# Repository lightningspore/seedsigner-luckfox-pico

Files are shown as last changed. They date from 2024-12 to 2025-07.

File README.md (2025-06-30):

# seedsigner-luckfox-pico
Port of the SeedSigner code to support the LuckFox Pico Linux board family. Since this device is still an embedded Linux device, like the Raspberry Pi, the changes are fairly minimal in order to access the buttons and the camera. This repo mostly pertains to the Buildroot OS build instructions, the KiCAD schematic and PCB design files, and 3D models of cases for the assembled device.

SeedSigner code fork: https://github.com/lightningspore/seedsigner/tree/0.8.5-luckfox

## Hardware Photos
_Most Recent Iteration: LuckFox Pico Mini B with no onboard SPI flash_
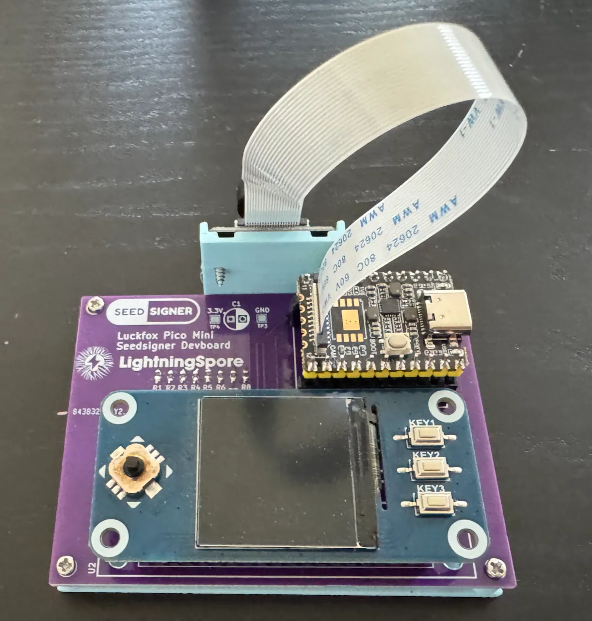
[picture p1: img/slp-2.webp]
LuckFox Pico Mini - SeedSigner

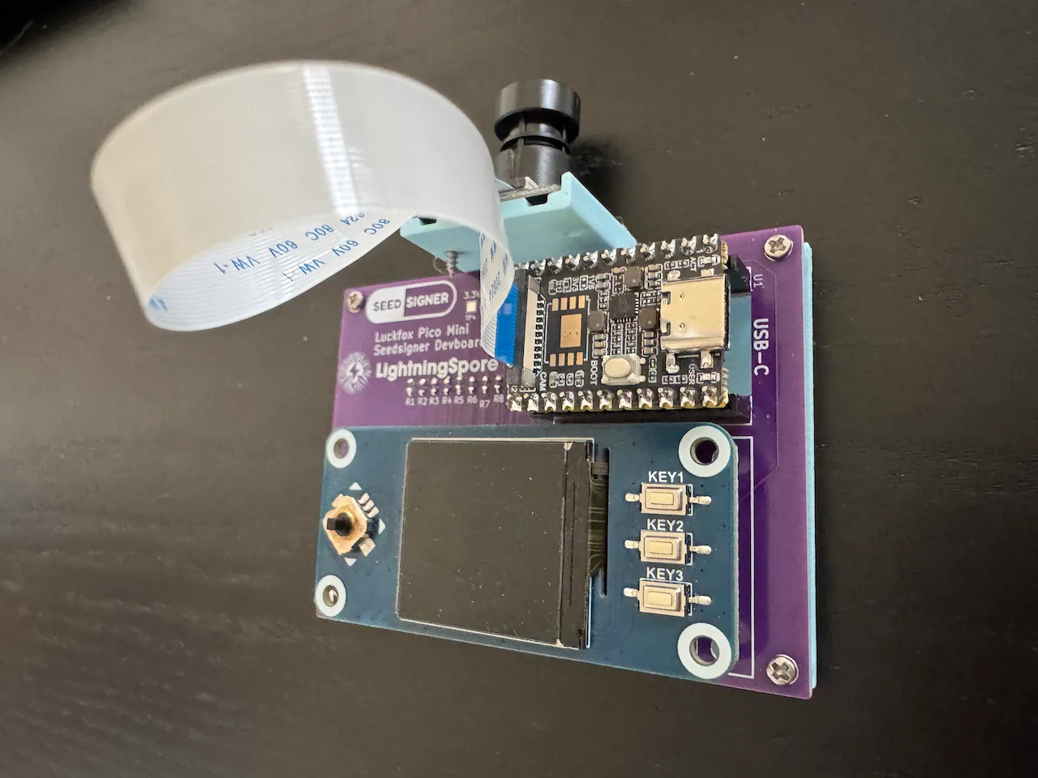
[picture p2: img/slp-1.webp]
LuckFox Pico Mini - SeedSigner 2


_Previous Iteration: LuckFox Pico Pro Max (More Flash, SPI Flash)_
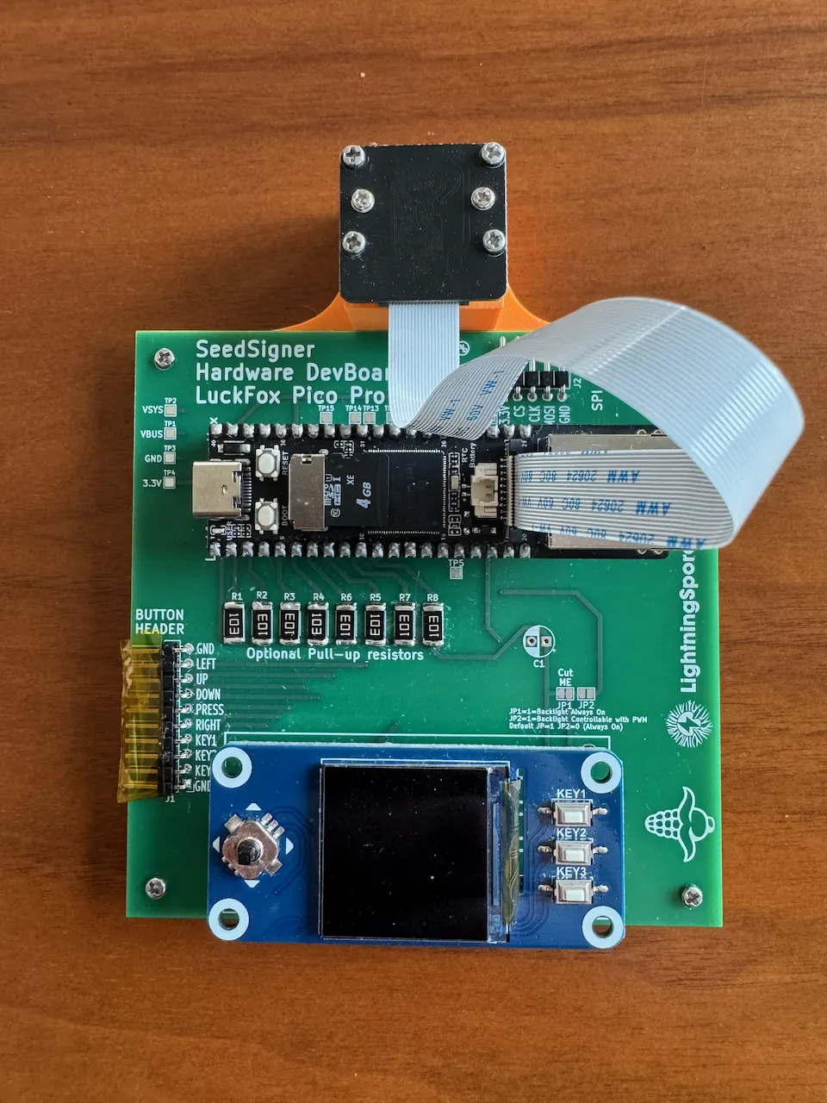
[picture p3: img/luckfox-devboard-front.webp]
LuckFox Pico Pro Max - SeedSigner

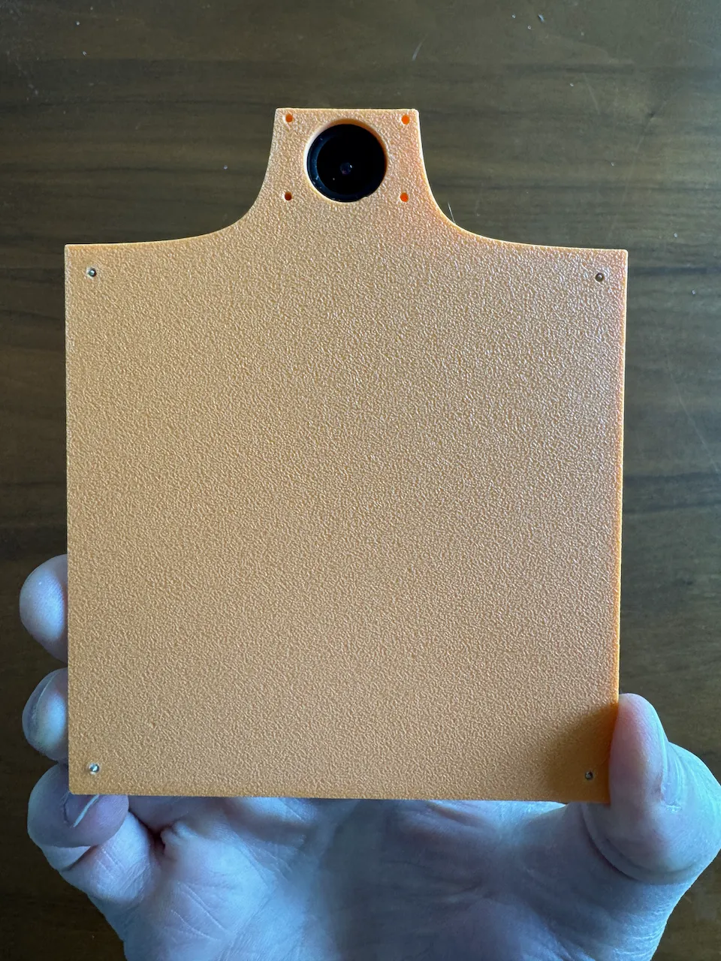
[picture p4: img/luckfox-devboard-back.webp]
Case From Behind


## Demo Videos

### First Look: SeedSigner running on LuckFox Pico Linux devboard
SeedSigner on LuckFox Pico Pro Max (https://www.youtube.com/watch?v=WHkOSn-lPG4)

## Materials Needed
Check out the shopping list for a parts list of various LuckFox-based hardware configurations: [here](docs/shopping_list.md)

These example builds can build a device for around $60.

## OS Image Build with Buildroot
The OS image is built using Buildroot in a Docker container. The complete build instructions, package requirements, and troubleshooting process are documented in [OS-build-instructions.md](docs/OS-build-instructions.md).

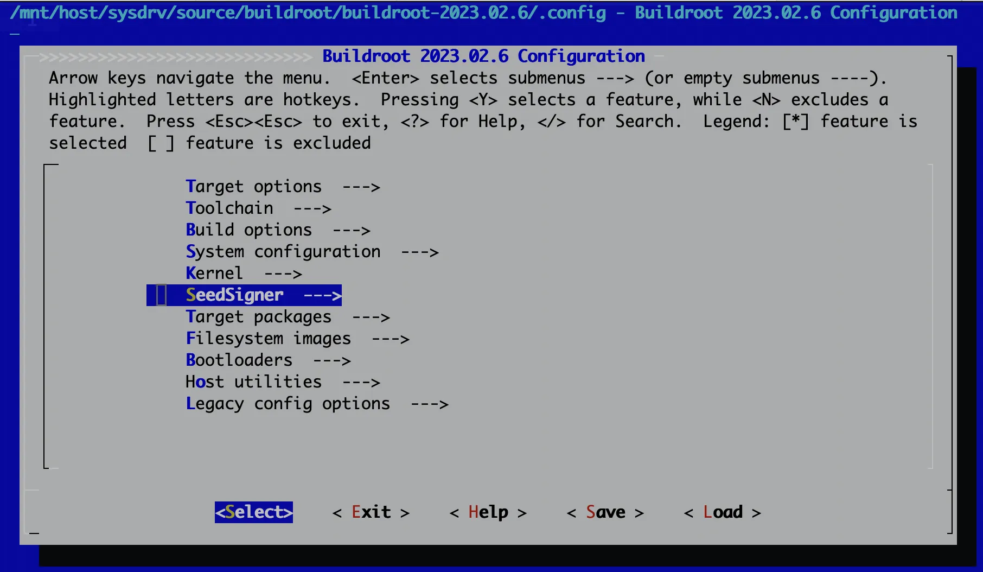
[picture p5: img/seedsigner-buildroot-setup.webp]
Buildroot Prompt


## Dev Machine Setup

### Install ADB
Developing for the LuckFox Pico device is quite convenient since the devices never connect to the internet and you can access the device shell using `adb`. You can push files back and forth to your dev machine, and you can access the device as a shell easily.
```
# mac
brew install homebrew/cask/android-platform-tools

# linux
sudo apt install android-tools-adb
```

### ADB Connection and Device Management

1. Connect to the device:
```
# List connected devices
adb devices

# Connect to device shell
adb shell
```

2. File Operations:
```
# Push files to device
adb push local_file.txt /remote/path/

# Sync the code repo for local development
adb push /repos/seedsigner/src /seedsigner

# Pull files from device
adb pull /seedsigner/config.json .

# List files on device
adb shell ls /path/to/directory
```

## Hardware Identification
Notice the left device has an empty PCB footprint pattern on it. This is where the optional SPI flash is soldered on. For the SeedSigner project we don't want permanent storage, so avoid devices with soldered SPI flash.

```
LEFT:  LuckFox Pico Mini A -> No Flash
RIGHT: LuckFox Pico Mini B -> Soldered Flash
```
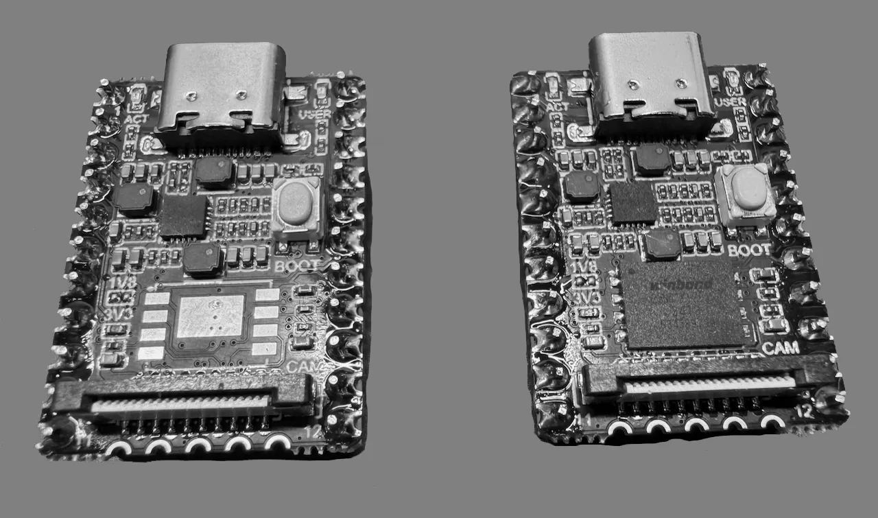
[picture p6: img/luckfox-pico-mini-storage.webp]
LuckFox Pico Mini


## Flashing the Device

### Flash MicroSD Card
```
sudo dd bs=4M status=progress if=seedsigner-luckfox-pico-YYYYmmdd_hhmmss.img of=/dev/diskX
```
Replace `/dev/diskX` with your actual SD card device path.

## LuckFox Pico OS Modifications
We have forked the [LuckFox Pico SDK](https://github.com/lightningspore/luckfox-pico) in order to enable various hardware features like pull-up resistors, adjust video RAM, and other things.

### Camera Memory
The LuckFox devotes some of its memory for camera-related algorithms, but we don't use this feature. Particularly on the LuckFox Pico Mini device, which only has 64MB of RAM, it is beneficial for us to reclaim a bit of this memory.

Memory usage WITHOUT modification:
```bash
[root@luckfox ]# free -h
              total        used        free      shared  buff/cache   available
Mem:          33.0M       24.3M        1.4M      476.0K        7.3M        5.4M
Swap:             0           0           0
```

Memory usage WITH modification:
```bash
[root@luckfox ]# free -h
              total        used        free      shared  buff/cache   available
Mem:          53.0M       23.6M        1.9M      472.0K       27.5M       25.3M
Swap:             0           0           0
```

### Pull-up Resistors
Our current dev board has external pull-up resistors, since we didn't know how to enable these at the time, and it is always smart to plan ahead when designing PCBs. NOTE: Even with this commit and this change, the internal pull-ups don't seem to work.

### SPI Buffer Size
While it is possible to send SPI data in chunks, you can increase the SPI buffer size to slightly increase throughput, which is useful for larger displays.

### PWM Output
In order to control the LCD screen backlight and support true dimming of the display (instead of just changing the background color of the QR code, for example), we had to enable a PWM on a specific output pin.

## Support the Developer
If you find this project helpful and would like to support its development, you can buy me a coffee! Your support helps keep this project going and funds future improvements. Help decentralize Bitcoin hardware!

Buy Me A Coffee (https://www.buymeacoffee.com/lightningspore)

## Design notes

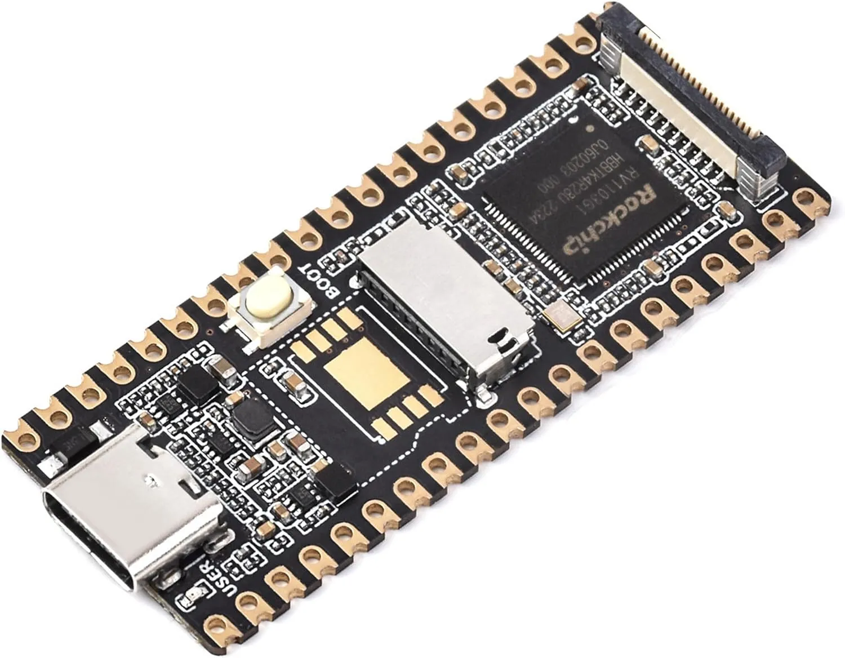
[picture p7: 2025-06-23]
img/luckfox-pico.webp

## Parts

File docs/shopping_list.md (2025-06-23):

# SeedSigner LuckFox Pico Shopping List

This document contains all the materials needed to build your own SeedSigner using the LuckFox Pico Pro/Max development board.

## Hardware Components
There are multiple PCB revisions available in this repository, some which support the Luckfox Pico Pro Max, with its two rows of 20 pins, and some designs supports the Luckfox Pico Mini, with its two rows of 11 pins.

Small form factor, no SPI flash:
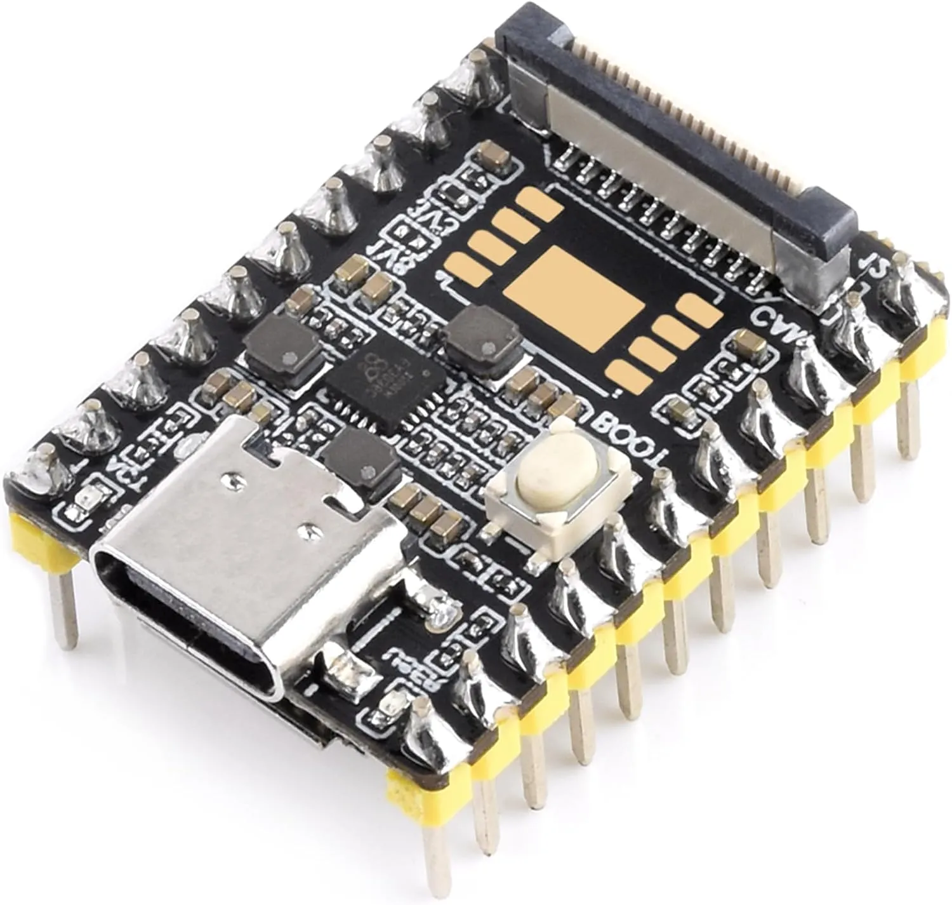
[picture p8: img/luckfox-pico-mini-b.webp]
Luckfox Pico Mini BM


Larger form factor, no SPI flash:
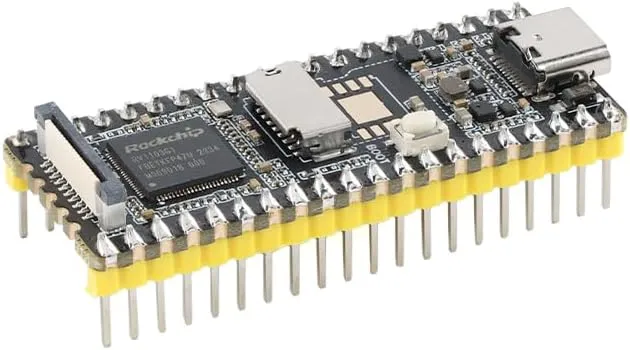
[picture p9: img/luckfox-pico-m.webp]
Luckfox Pico M


Larger form factor, SPI flash, ethernet port:
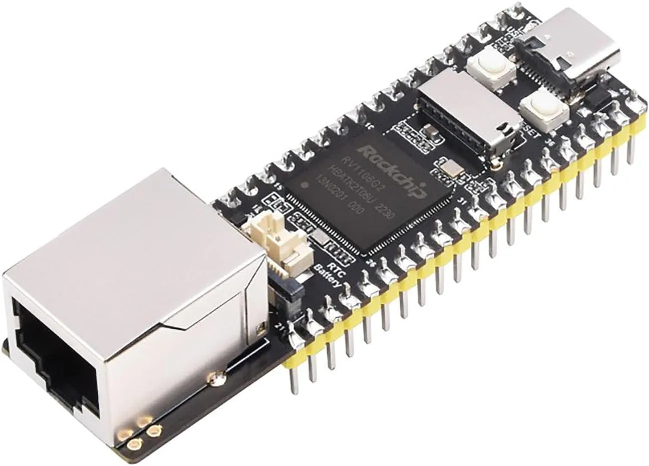
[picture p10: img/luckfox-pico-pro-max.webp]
Luckfox Pico Pro Max


### Core Components
| Item | Price | Link | Notes |
|---|---|---|---|
| LuckFox Pico Pro Max | $20 | [Amazon](https://www.amazon.com/dp/B0D6QVC178) | Main development board |
| LuckFox Pico Mini-BM | $8 | [Amazon](https://www.amazon.com//dp/B0D6VSMND4) | Main development board 2 |

| LuckFox Camera SC3336 | $16 | [Amazon](https://www.amazon.com/dp/B0CJM7S6F6) | Camera module for QR code scanning |
| SeedSigner LCD Button Board | $16 | [Amazon](https://www.amazon.com/dp/B07FDX5PJY) | Display and button interface |

### Connectors & Headers
| Item | Price | Link | Notes |
|---|---|---|---|
| 40 Pin Header | $1 | [Amazon](https://www.amazon.com/dp/B01461DQ6S) | For connecting components |
| 2 x Row Header Male | $0.25 | [Amazon](https://www.amazon.com/dp/B07R5QDL8D) | Additional connectors |

### Custom Parts
| Item | Price | Link | Notes |
|---|---|---|---|
| Custom PCB | $5 | TODO: Link to PCB sales | Custom circuit board |
| 3D Printed Case | $2 | TODO: Link to 3D Printed Case sales | Enclosure for the device |

## Total Cost
**Estimated Total: ~$60** (when ordering from Amazon)

## MicroSD Cards
| Item | Price | Link | Notes |
|---|---|---|---|
| ATP Electronics AF4GUD3A-WAAXX | $13.51 | [DigiKey](https://www.digikey.com/en/products/detail/atp-electronics-inc/AF4GUD3A-WAAXX/5361062) | Recommended microSD card for flashing the custom OS image |

## Hardware Identification Notes

When purchasing the LuckFox Pico board, make sure to get the version **without** the SPI flash footprint. The left device in the reference image shows the correct version with an empty PCB footprint pattern. For the SeedSigner project, we don't want permanent storage, so avoid devices that have the SPI flash already soldered on.

Luckfox Pico Mini

---

*Note: Prices and availability may vary. This list was compiled based on the project documentation and may need updates as components become available or prices change.*

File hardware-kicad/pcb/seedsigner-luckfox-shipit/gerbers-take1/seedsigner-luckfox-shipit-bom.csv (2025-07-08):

Id | Comment | Designator | Footprint | Quantity | JLCPCB Part#(optional) | Comment
1 | Header 8 Pos | LCD1 | ST7789_LCD_MOD1 | 1 | C190820
4 | Resistor 0805 10Kohm | R8,R4,R3,R7,R5,R1,R2,R6 | R_0805_2012Metric_Pad1.20x1.40mm_HandSolder | 8 | C25612
8 | 2 X 20pos 2.54 row header female | U1,U2 | LUCKFOX_PICO | 2 | C25503124

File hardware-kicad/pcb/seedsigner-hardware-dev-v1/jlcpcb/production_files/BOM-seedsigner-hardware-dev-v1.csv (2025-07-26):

Comment | Designator | Footprint | LCSC | Quantity
PCA9539PW_112 | U5 | SOP65P640X110-24N | C129516 | 1
Conn_01x04 | J1 | NS-Tech_Grove_1x04_P2mm_Vertical | C157926 | 1
10K | R1,R10,R11,R12,R13,R14,R2,R3,R4,R5,R6,R7,R8,R9 | R_0805_2012Metric_Pad1.20x1.40mm_HandSolder | C17414 | 14
ST7789 | LCD1,LCD2 | PinHeader_1x08_P2.54mm_Vertical | C190820 | 2
LuckFox_Pico_PLUS_PRO | U4,U6 | LUCKFOX_PICO | C25503124 | 1
RPI_ZERO | U3 | RPi_Zero | C2685093 | 1
0.1uF | C1 | C_0805_2012Metric_Pad1.18x1.45mm_HandSolder | C49678 | 1
WAVESHARE_LCD_BUTTON_BOARD_1.3in | U2 | WAVESHARE_LCD_BUTTON | C5224014 | 1
SW_Push | SW5 | BTN_SPST_NO_PTH |  | 1
TestPoint | TP6 | TestPoint_Pad_D1.0mm |  | 1
SW_Push | SW6 | BTN_SPST_NO_PTH |  | 1
SW_Push | SW2 | BTN_SPST_NO_PTH |  | 1
TestPoint | TP4 | TestPoint_Pad_D1.0mm |  | 1
SW_Push | SW3 | BTN_SPST_NO_PTH |  | 1
TestPoint | TP2 | TestPoint_Pad_D1.0mm |  | 1
SW_Push | SW7 | BTN_SPST_NO_PTH |  | 1
SW_Push | SW1 | BTN_SPST_NO_PTH |  | 1
TestPoint | TP1 | TestPoint_Pad_D1.0mm |  | 1
TestPoint | TP3 | TestPoint_Pad_D1.0mm |  | 1
SW_Push | SW8 | BTN_SPST_NO_PTH |  | 1
TestPoint | TP5 | TestPoint_Pad_D1.0mm |  | 1
SW_Push | SW4 | BTN_SPST_NO_PTH |  | 1
TestPoint | TP9 | TestPoint_Pad_D1.0mm |  | 1
TestPoint | TP7 | TestPoint_Pad_D1.0mm |  | 1
TestPoint | TP10 | TestPoint_Pad_D1.0mm |  | 1
TestPoint | TP8 | TestPoint_Pad_D1.0mm |  | 1

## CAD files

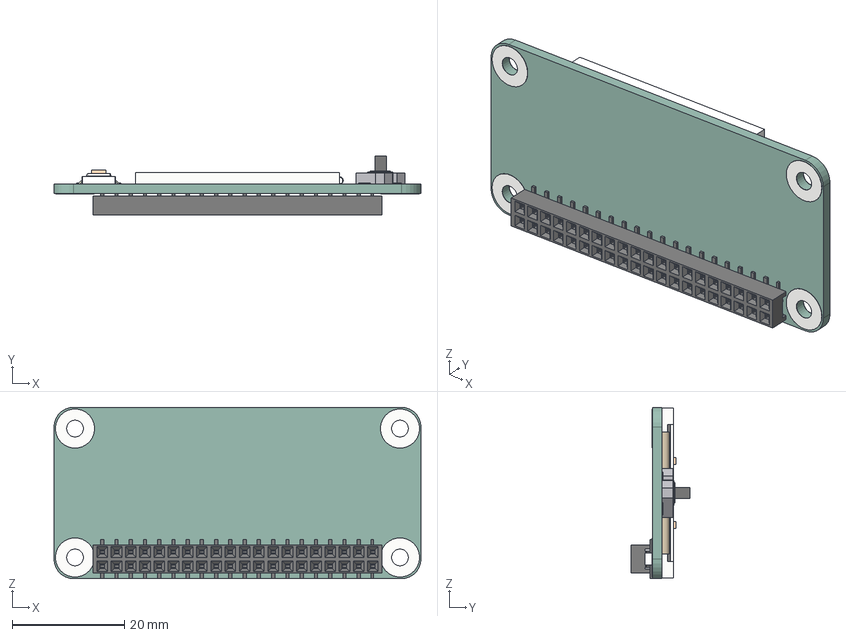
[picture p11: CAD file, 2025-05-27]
hardware-kicad/3d_models/WaveShare 1.44inch LCD HAT v1.step
65.5 x 10.5 x 30.6 mm
silk
glass
plume
joystick
G73 button x 3
DS1023-2x20S v2

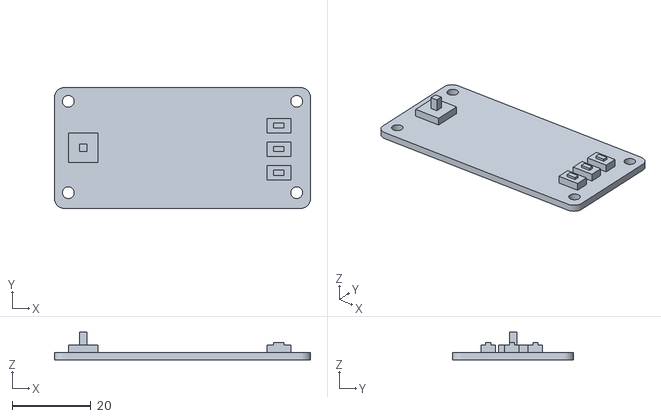
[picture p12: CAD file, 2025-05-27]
hardware-kicad/3d_models/waveshare_lcd_hat.stl
65.0 x 30.7 x 7.00

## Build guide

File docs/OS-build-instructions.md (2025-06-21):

# OS Build Instructions

## Setup the Docker build environment
Run these commands from `buildroot` directory.

Build the builder image:
```bash
cd buildroot/
docker build -t foxbuilder:latest .
```

*IMPORTANT* We need all of these directories to be setup, and cloned in our `$HOME` directory:
```bash
ls ~
luckfox-pico  seedsigner  seedsigner-luckfox-pico  seedsigner-os
```
The `seedsigner-luckfox-pico` directory is this repo we are already in!

Clone the Luckfox SDK repo:
```bash
git clone https://github.com/lightningspore/luckfox-pico.git \
    --depth=1 --single-branch
```

Clone the Seedsigner OS repo:
```bash
git clone https://github.com/seedsigner/seedsigner-os.git \
    --depth=1 --single-branch
```

Clone the Seedsigner repo:
```bash
git clone https://github.com/lightningspore/seedsigner.git \
    --depth=1 -b luckfox-dev --single-branch
```

## Run OS Build

Run these commands from `buildroot/` directory. This is the directory/repo we cloned above.

```bash
LUCKFOX_SDK_DIR=$HOME/luckfox-pico
SEEDSIGNER_CODE_DIR=$HOME/seedsigner
LUCKFOX_BOARD_CFG_DIR=$HOME/seedsigner-luckfox-pico
SEEDSIGNER_OS_DIR=$HOME/seedsigner-os

# TODO check all these above paths exist

docker run -d --name luckfox-builder \
    -v $LUCKFOX_SDK_DIR:/mnt/host \
    -v $SEEDSIGNER_CODE_DIR:/mnt/ss \
    -v $LUCKFOX_BOARD_CFG_DIR:/mnt/cfg \
    -v $SEEDSIGNER_OS_DIR:/mnt/ssos \
    foxbuilder:latest
```

These below commands are run INSIDE of the docker image.

Enter the container:
```bash
docker exec -it luckfox-builder bash
```

Start the build:
```bash
/mnt/cfg/buildroot/add_package_buildroot.sh
```

This commands sets the build targets:
Select, Pico Pro Max, buildroot, and SPI.
```bash
# set build configuration
./build.sh lunch
```

This command allows us to choose what packages to install into our OS image.
```bash
# configure packages to install in buildroot
./build.sh buildrootconfig
```

Buildroot Setup

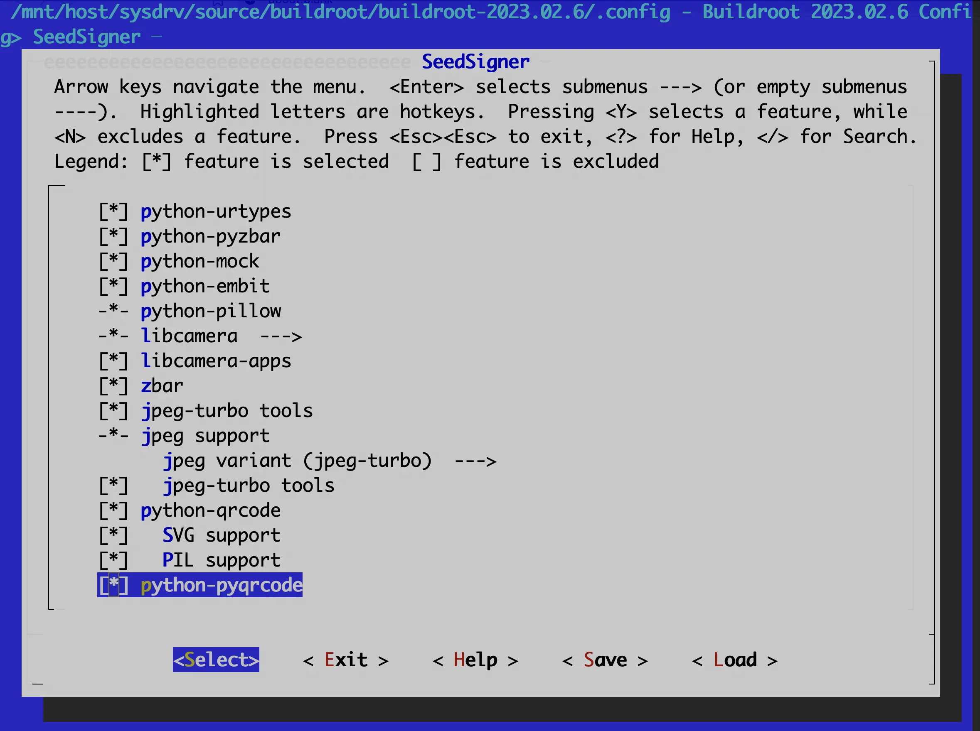
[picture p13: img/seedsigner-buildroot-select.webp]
Buildroot Package Selection


After selecting all the above packages, SAVE the configuration.
The configuration is saved at: `sysdrv/source/buildroot/buildroot-2023.02.6/.config`

You can sanity check your configuration to ensure the selected packages have been enabled like so:
```bash
cat sysdrv/source/buildroot/buildroot-2023.02.6/.config | grep "LIBCAMERA"
cat sysdrv/source/buildroot/buildroot-2023.02.6/.config | grep "ZBAR"
cat sysdrv/source/buildroot/buildroot-2023.02.6/.config | grep "LIBJPEG"
...
```

A final sanity check, this shows all enabled packages... This might be useful as we try and remove any unnecessary packages from the build:
```bash
cat sysdrv/source/buildroot/buildroot-2023.02.6/.config | grep -v "^#"
```

### Adding Custom Packages
If you need to add custom packages to the buildroot configuration, you can use the `add_package_buildroot.sh` script. This script:
1. Adds SeedSigner-specific packages to the buildroot configuration
2. Copies necessary package files from the seedsigner-os repository
3. Updates Python paths and configurations
4. Adds required dependencies like python-pyzbar, python-embit, and camera-related packages

To use the script:
```bash
# From the buildroot directory
./add_package_buildroot.sh
```

This command will use one of the saved configurations for the build:
```bash
# Use config from repo
cp ../configs/config_20241218184332.config sysdrv/source/buildroot/buildroot-2023.02.6/.config

# Sanity check the configuration was loaded properly
# Selected packages like ZBAR should be listed as enabled here
./build.sh buildrootconfig
```

Start the image compilation process:
```bash
./build.sh uboot
./build.sh kernel
./build.sh rootfs
# needed for camera libs
./build.sh media
```

Verify all of the .img files are there:
```bash
$ ls /mnt/host/output/out/           
S20linkmount  media_out  rootfs_uclibc_rv1106  sysdrv_out

$ ls /mnt/host/output/image/
boot.img  download.bin  idblock.img  uboot.img
```

Copy over app code and pin configs
```bash
# Pin configs
cp /mnt/cfg/config/luckfox.cfg /mnt/host/output/out/rootfs_uclibc_rv1106/etc/luckfox.cfg

# Seedsigner code
cp -r /mnt/ss/src/ /mnt/host/output/out/rootfs_uclibc_rv1106/seedsigner
```

Package:
```bash
# Package up the pieces
./build.sh firmware
```

Double check the output, now all of the expected .img files are there:
```bash
$ ls /mnt/host/output/image/
boot.img  download.bin  env.img  idblock.img  oem.img  rootfs.img  sd_update.txt  tftp_update.txt  uboot.img  update.img  userdata.img
```

Final Piece of Sanity Checking:
```bash
dbg='yes' ./tools/linux/Linux_Upgrade_Tool/rkdownload.sh -d output/image/
```

Package into single flashable ISO image:
```bash
cd /mnt/host/output/image
/mnt/cfg/buildroot/blkenvflash seedsigner-luckfox-pico.img
```

Send back to dev machine (if building on a remote X86 machine):
```bash
scp ubuntu@11.22.33.44:/home/ubuntu/seedsigner-luckfox-pico/buildroot/luckfox-pico/output/image/seedsigner-luckfox-pico.img ~/Downloads
```

Flash to MicroSD Card:
```bash
sudo dd bs=4M \
    status=progress \
    if=/Users/lightningspore/Downloads/seedsigner-luckfox-pico.img \
    of=/dev/disk8
```

Put MicroSD Card into Luckfox Pico Device.

```bash
adb shell
```

TODO: Link to next steup in the install/setup process

## Official resources

[Luckfox Pico Official Flashing Guide](https://wiki.luckfox.com/Luckfox-Pico/Linux-MacOS-Burn-Image/) - Official documentation for flashing images to the Luckfox Pico device on Linux and macOS systems

## Hardware Device Overlay Config
```
cat luckfox-pico/sysdrv/source/kernel/arch/arm/boot/dts/rv1103g-luckfox-pico.dts
cat luckfox-pico/sysdrv/source/kernel/arch/arm/boot/dts/rv1103.dtsi
cat luckfox-pico/sysdrv/source/kernel/arch/arm/boot/dts/rv1103-luckfox-pico-ipc.dtsi
cat luckfox-pico/sysdrv/source/kernel/arch/arm/boot/dts/rv1106-evb.dtsi
```

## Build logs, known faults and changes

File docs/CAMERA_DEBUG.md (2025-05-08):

## Ensure CSI is enabled
```bash
cat /etc/luckfox.cfg
```

## Check i2c
```bash
i2cdetect -y 4
```

Check whether 0x30 is UU to verify camera connectivity

```
[root@luckfox ]# which rkipc
/oem/usr/bin/rkipc
```

./

## Forum Links

- [Post 1: I2C and rkisp](https://forums.luckfox.com/viewtopic.php?t=1133)

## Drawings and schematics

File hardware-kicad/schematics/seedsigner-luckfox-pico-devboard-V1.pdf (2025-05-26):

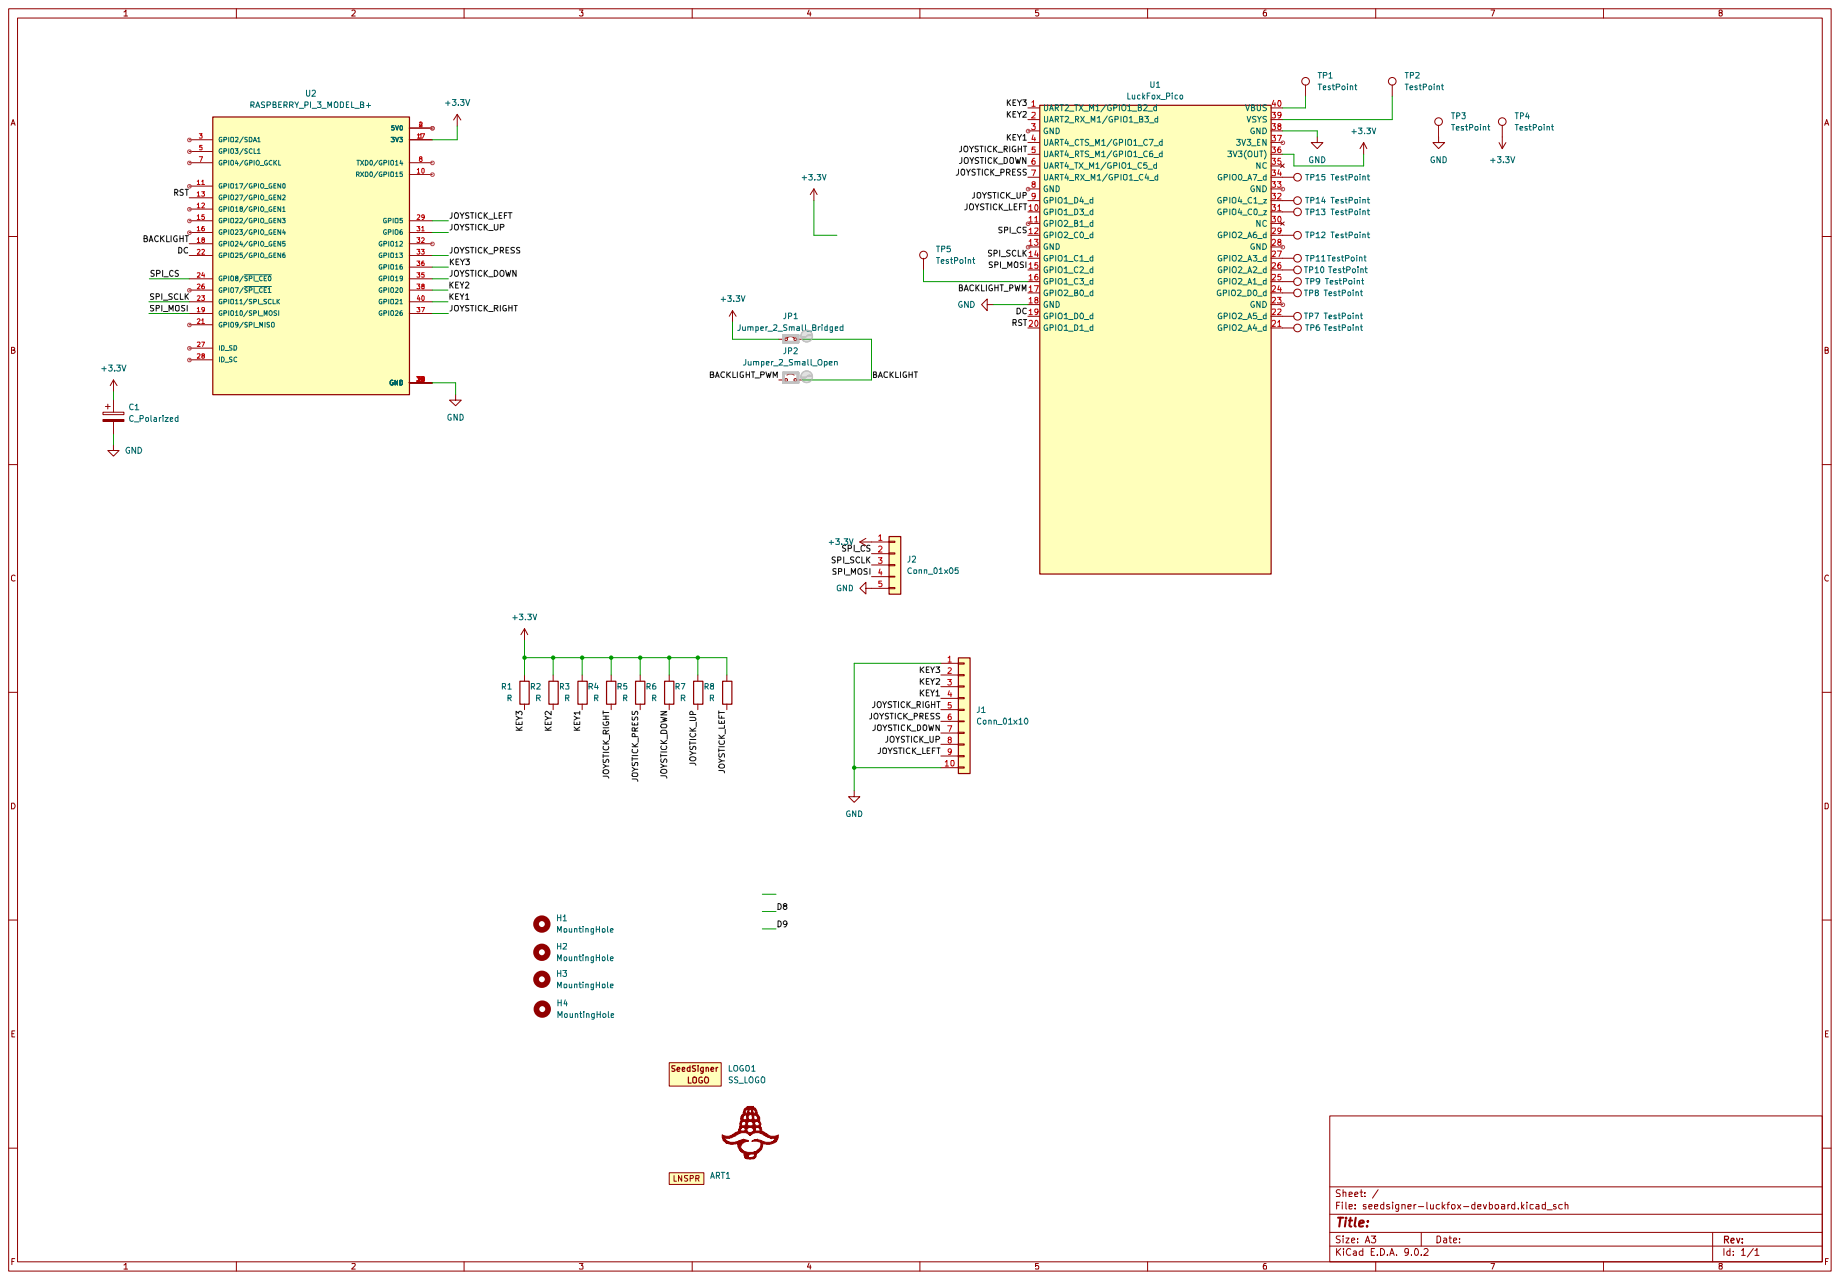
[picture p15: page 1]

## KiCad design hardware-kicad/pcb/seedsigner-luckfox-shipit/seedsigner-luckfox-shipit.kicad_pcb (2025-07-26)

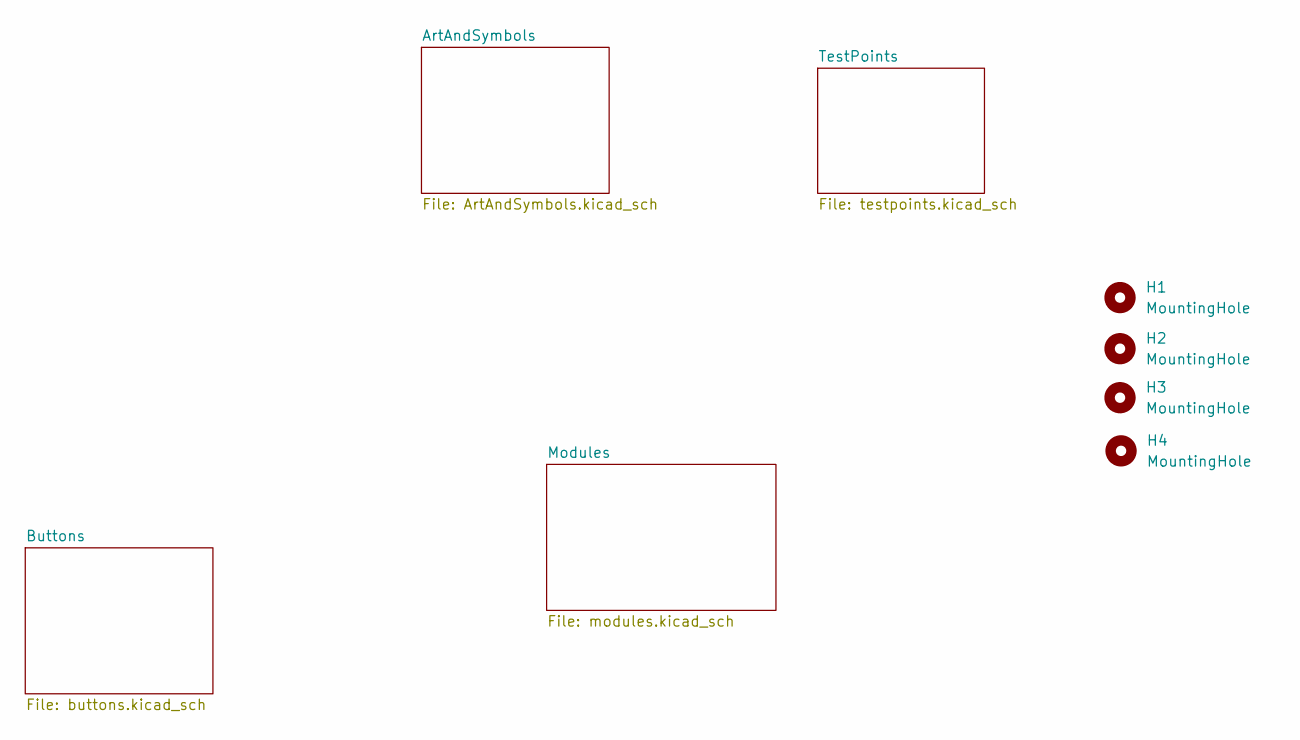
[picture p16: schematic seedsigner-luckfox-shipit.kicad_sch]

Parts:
H1, H2, H3, H4: MountingHole; MOUNT_HOLE_3MM

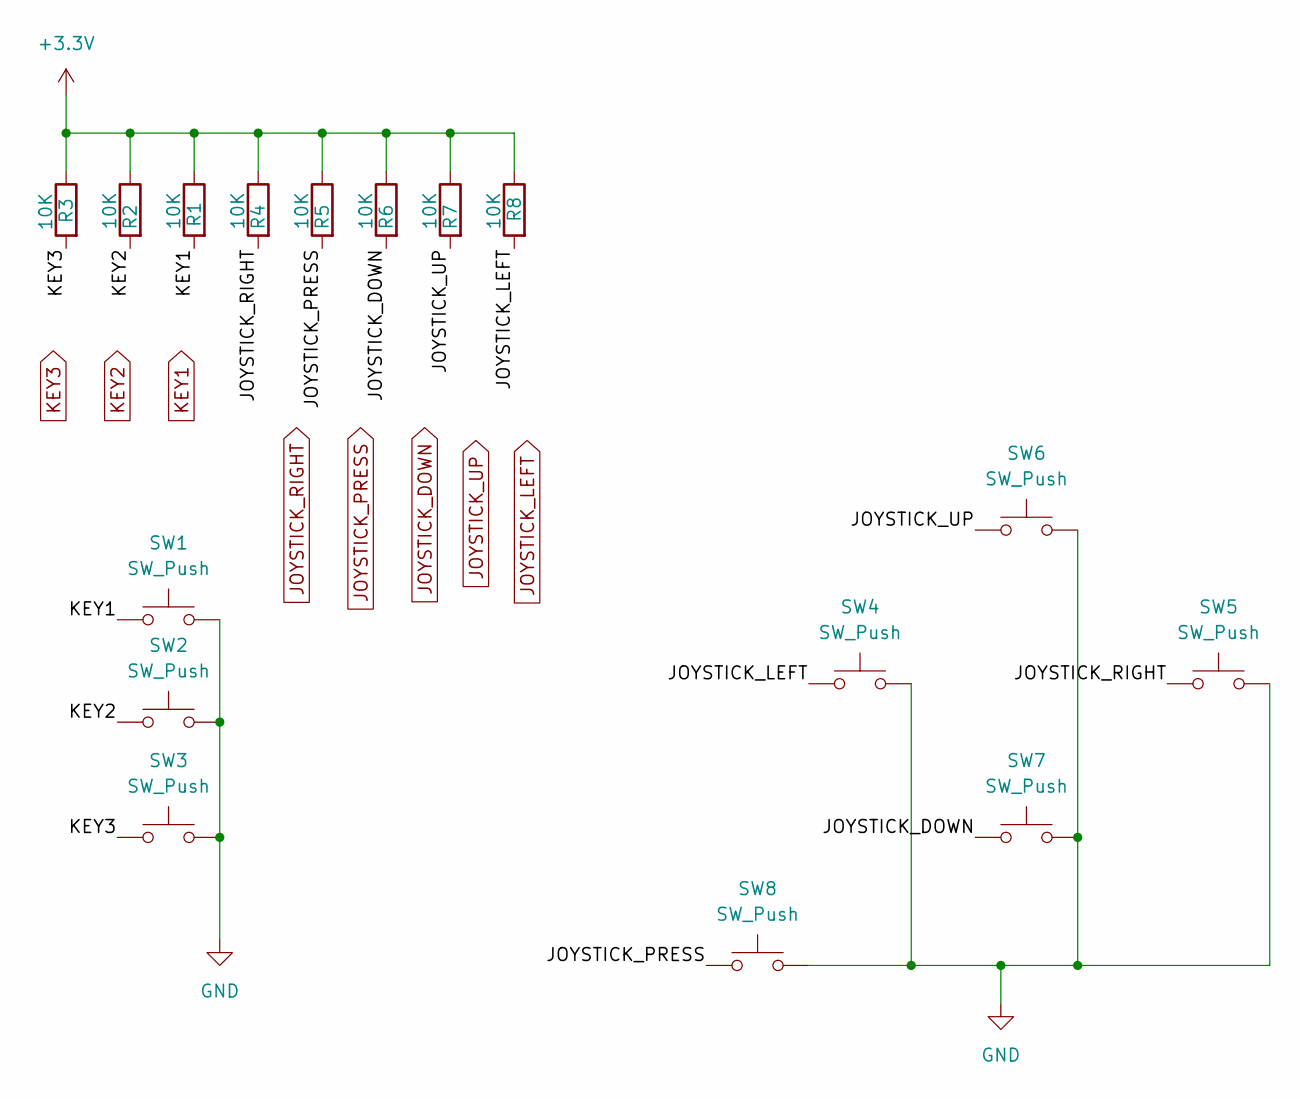
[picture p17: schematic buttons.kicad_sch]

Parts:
R1, R2, R3, R4, R5, R6, R7, R8: 10K; R_0805_2012Metric_Pad1.20x1.40mm_HandSolder
SW1, SW2, SW3, SW4, SW5, SW6, SW7, SW8: SW_Push; BTN_SPST_NO_PTH

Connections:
+3.3V: R1.1, R2.1, R3.1, R4.1, R5.1, R6.1, R7.1, R8.1; also elsewhere on the board
GND: SW1.2, SW2.2, SW3.2, SW4.2, SW5.2, SW6.2, SW7.2, SW8.2; also elsewhere on the board
JOYSTICK_DOWN: R6.2, SW7.1; also elsewhere on the board
JOYSTICK_LEFT: R8.2, SW4.1; also elsewhere on the board
JOYSTICK_PRESS: R5.2, SW8.1; also elsewhere on the board
JOYSTICK_RIGHT: R4.2, SW5.1; also elsewhere on the board
JOYSTICK_UP: R7.2, SW6.1; also elsewhere on the board
KEY1: R1.2, SW1.1; also elsewhere on the board
KEY2: R2.2, SW2.1; also elsewhere on the board
KEY3: R3.2, SW3.1; also elsewhere on the board

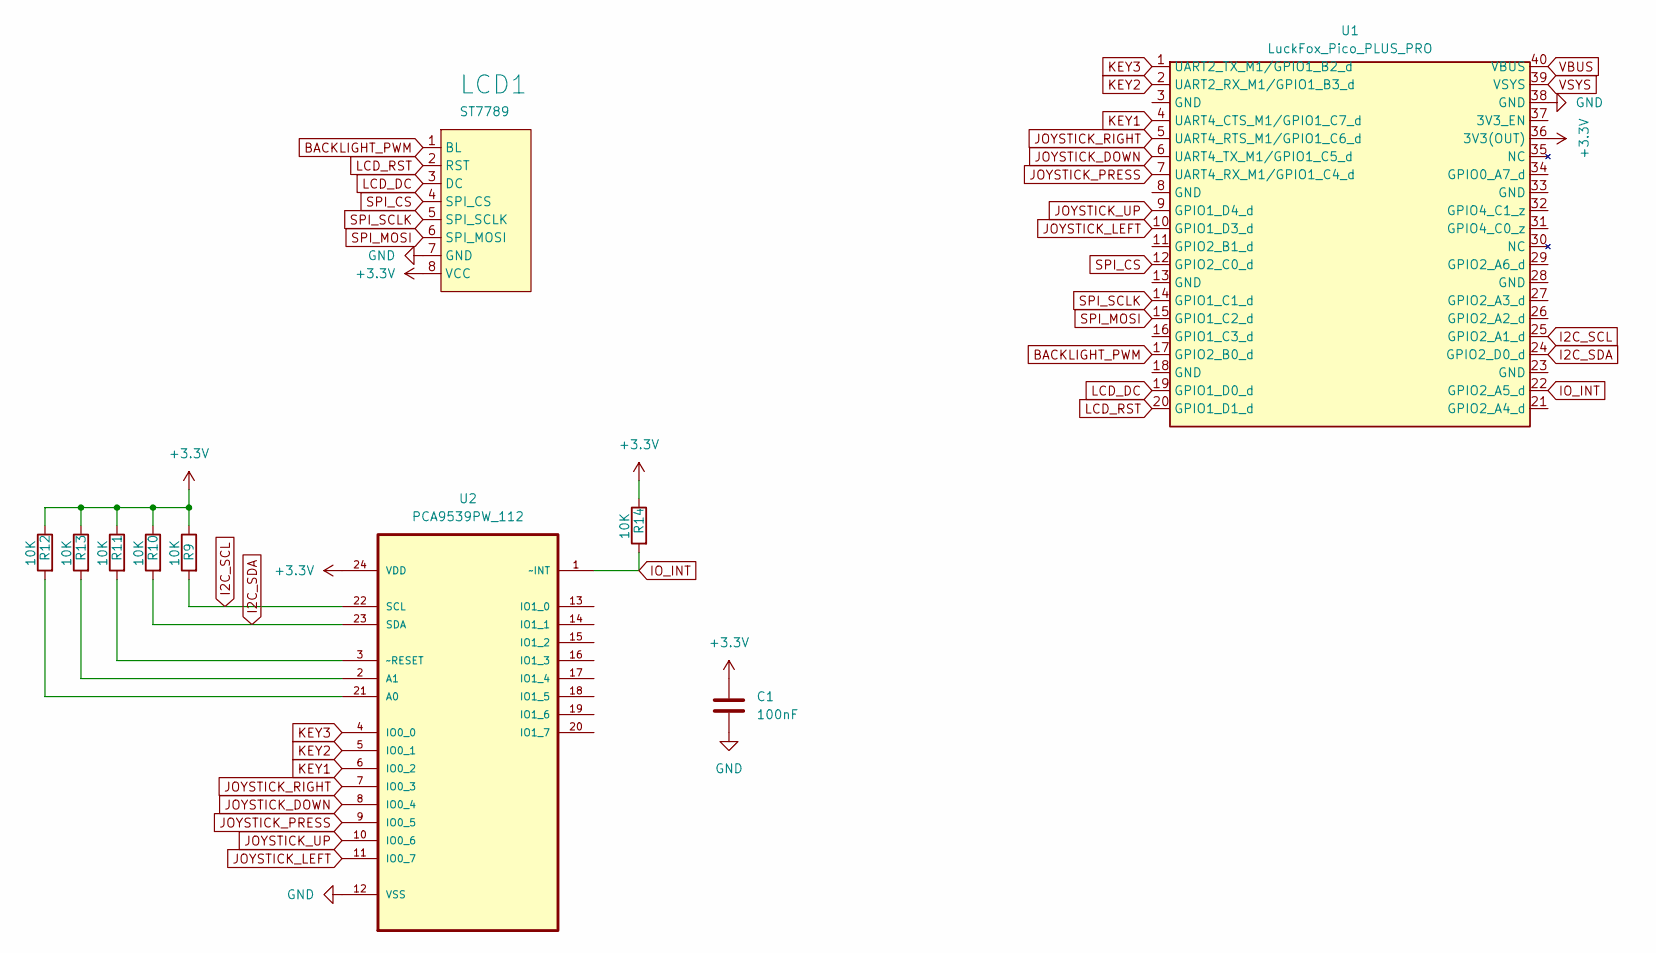
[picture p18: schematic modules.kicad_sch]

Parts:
C1: 100nF; C_0805_2012Metric_Pad1.18x1.45mm_HandSolder
LCD1: ST7789; ST7789_LCD_MOD1
R9, R10, R11, R12, R13, R14: 10K; R_0805_2012Metric_Pad1.20x1.40mm_HandSolder
U1: LuckFox_Pico_PLUS_PRO; LUCKFOX_PICO
U2: PCA9539PW_112; SOP65P640X110-24N; MPN PCA9539PW,112

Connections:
+3.3V: C1.1, LCD1.8 (VCC), R9.1, R10.1, R11.1, R12.1, R13.1, R14.1, U1.36 (3V3(OUT)), U2.24 (VDD); also elsewhere on the board
BACKLIGHT_PWM: LCD1.1 (BL), U1.17 (GPIO2_B0_d)
GND: C1.2, LCD1.7 (GND), U1.38 (GND), U2.12 (VSS); also elsewhere on the board
I2C_SCL: R9.2, U1.25 (GPIO2_A1_d), U2.22 (SCL)
I2C_SDA: R10.2, U1.24 (GPIO2_D0_d), U2.23 (SDA)
IO_INT: R14.2, U1.22 (GPIO2_A5_d), U2.1 (~INT)
JOYSTICK_DOWN: U1.6 (UART4_TX_M1/GPIO1_C5_d), U2.8 (IO0_4); also elsewhere on the board
JOYSTICK_LEFT: U1.10 (GPIO1_D3_d), U2.11 (IO0_7); also elsewhere on the board
JOYSTICK_PRESS: U1.7 (UART4_RX_M1/GPIO1_C4_d), U2.9 (IO0_5); also elsewhere on the board
JOYSTICK_RIGHT: U1.5 (UART4_RTS_M1/GPIO1_C6_d), U2.7 (IO0_3); also elsewhere on the board
JOYSTICK_UP: U1.9 (GPIO1_D4_d), U2.10 (IO0_6); also elsewhere on the board
KEY1: U1.4 (UART4_CTS_M1/GPIO1_C7_d), U2.6 (IO0_2); also elsewhere on the board
KEY2: U1.2 (UART2_RX_M1/GPIO1_B3_d), U2.5 (IO0_1); also elsewhere on the board
KEY3: U1.1 (UART2_TX_M1/GPIO1_B2_d), U2.4 (IO0_0); also elsewhere on the board
LCD_DC: LCD1.3 (DC), U1.19 (GPIO1_D0_d)
LCD_RST: LCD1.2 (RST), U1.20 (GPIO1_D1_d)
unnamed: R12.2, U2.21 (A0)
unnamed: R13.2, U2.2 (A1)
unnamed: R11.2, U2.3 (~RESET)
SPI_CS: LCD1.4 (SPI_CS), U1.12 (GPIO2_C0_d)
SPI_MOSI: LCD1.6 (SPI_MOSI), U1.15 (GPIO1_C2_d)
SPI_SCLK: LCD1.5 (SPI_SCLK), U1.14 (GPIO1_C1_d)
VBUS: U1.40 (VBUS); also elsewhere on the board
VSYS: U1.39 (VSYS); also elsewhere on the board

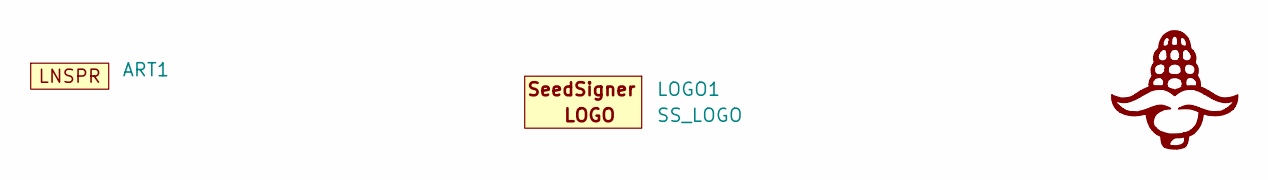
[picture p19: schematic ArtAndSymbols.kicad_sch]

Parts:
ART1: LightningSpore_Logo
LOGO1: SS_LOGO; seedsigner-logo-small
LOGO2: CORN-LOGO; corn-logo

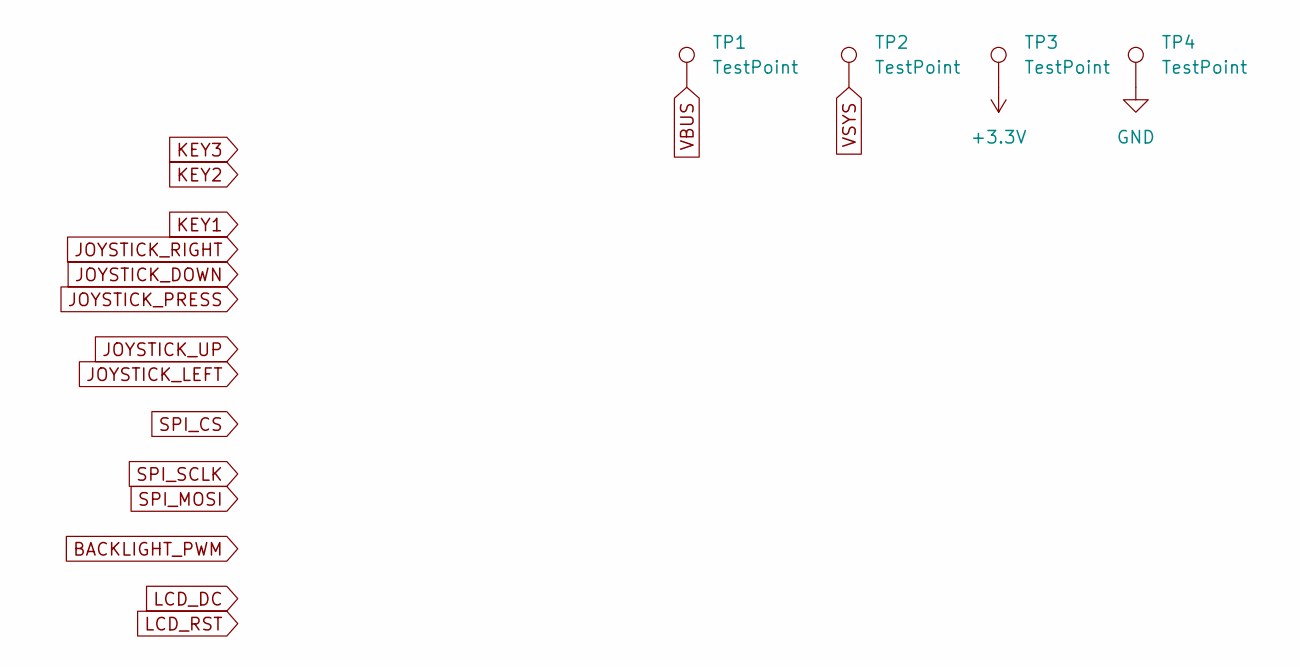
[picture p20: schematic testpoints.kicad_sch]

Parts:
TP1, TP2, TP3, TP4: TestPoint; TestPoint_Pad_1.5x1.5mm

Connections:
+3.3V: TP3.1; also elsewhere on the board
GND: TP4.1; also elsewhere on the board
VBUS: TP1.1; also elsewhere on the board
VSYS: TP2.1; also elsewhere on the board

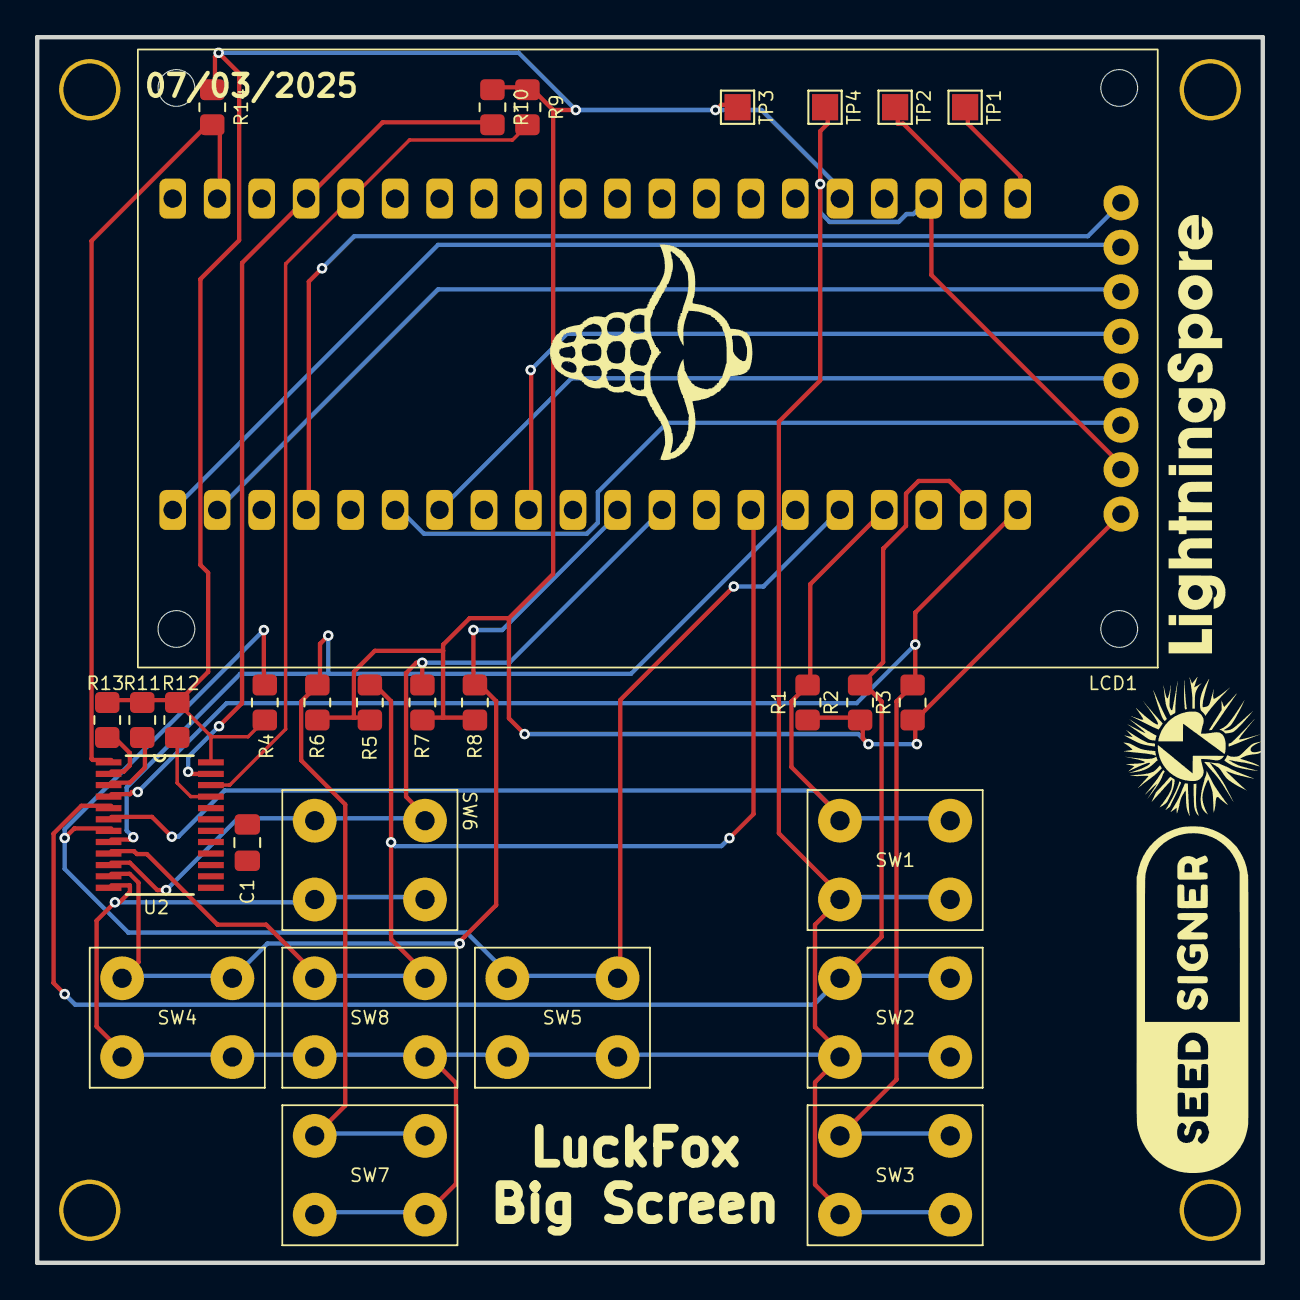
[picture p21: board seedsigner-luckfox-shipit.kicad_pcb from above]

Board: 2 copper layers, 70.0 x 70.0 mm, 37 parts (1 on the bottom side), 24 nets.

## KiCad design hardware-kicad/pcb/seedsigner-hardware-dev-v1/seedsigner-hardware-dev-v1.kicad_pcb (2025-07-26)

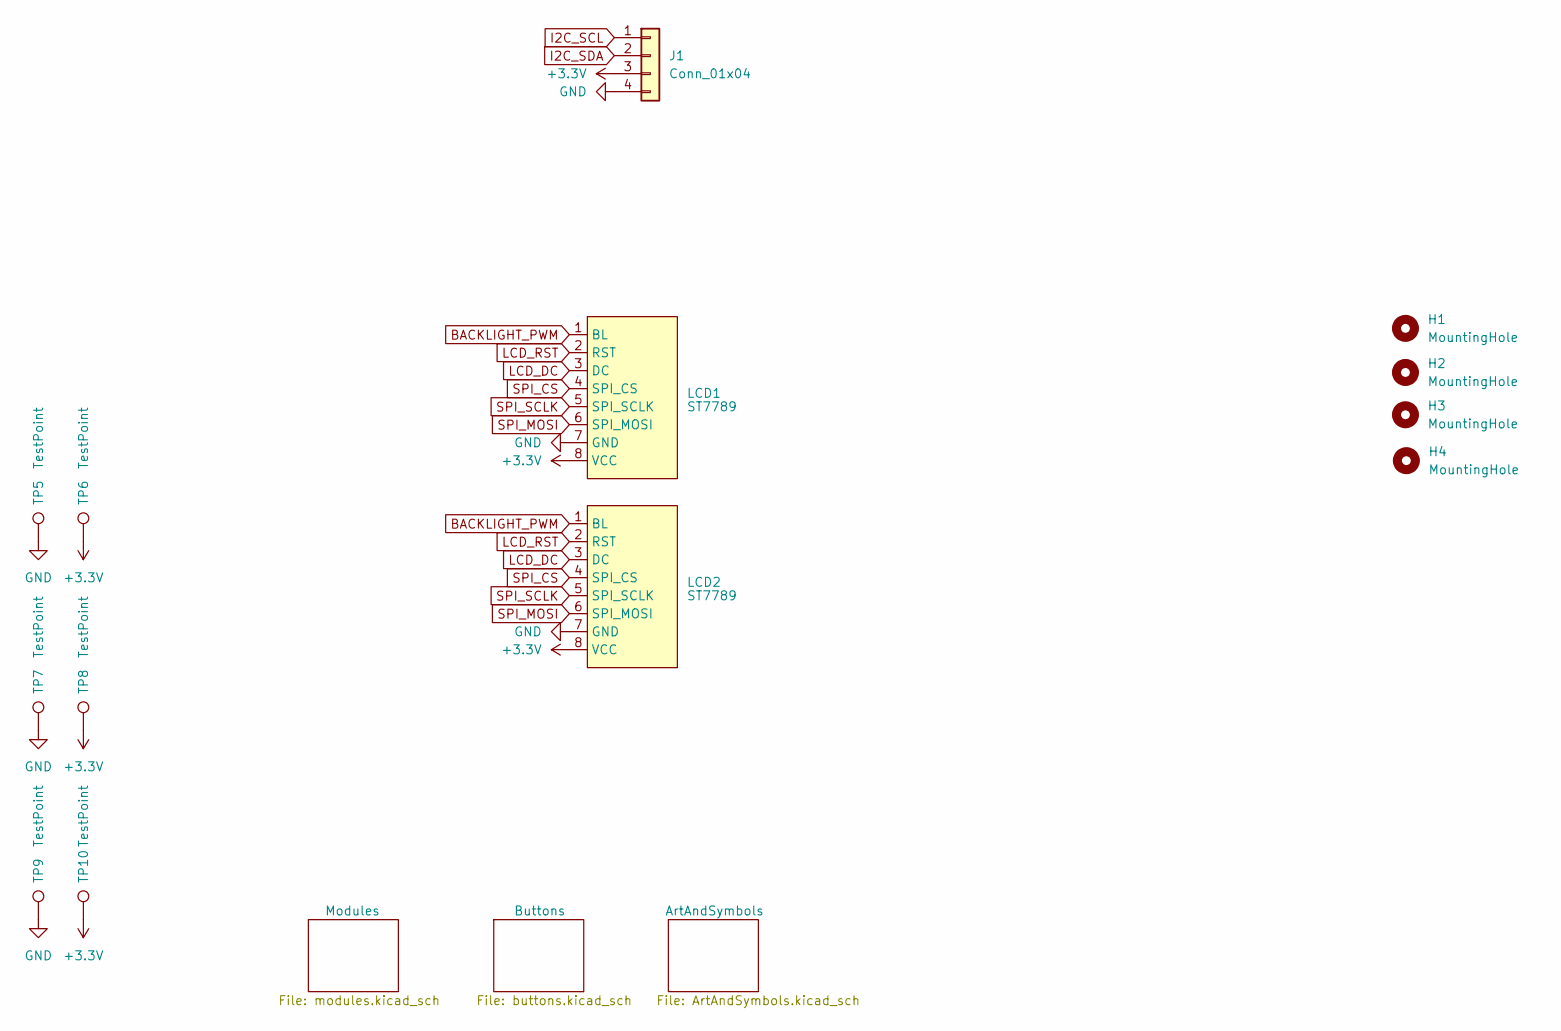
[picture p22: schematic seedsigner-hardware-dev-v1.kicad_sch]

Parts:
H1, H2, H3, H4: MountingHole; MOUNT_HOLE_3MM
J1: Conn_01x04; NS-Tech_Grove_1x04_P2mm_Vertical
LCD1, LCD2: ST7789; PinHeader_1x08_P2.54mm_Vertical
TP5, TP6, TP7, TP8, TP9, TP10: TestPoint; TestPoint_Pad_D1.0mm

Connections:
+3.3V: J1.3, LCD1.8 (VCC), LCD2.8 (VCC), TP6.1, TP8.1, TP10.1; also elsewhere on the board
BACKLIGHT_PWM: LCD1.1 (BL), LCD2.1 (BL); also elsewhere on the board
GND: J1.4, LCD1.7 (GND), LCD2.7 (GND), TP5.1, TP7.1, TP9.1; also elsewhere on the board
I2C_SCL: J1.1; also elsewhere on the board
I2C_SDA: J1.2; also elsewhere on the board
LCD_DC: LCD1.3 (DC), LCD2.3 (DC); also elsewhere on the board
LCD_RST: LCD1.2 (RST), LCD2.2 (RST); also elsewhere on the board
SPI_CS: LCD1.4 (SPI_CS), LCD2.4 (SPI_CS); also elsewhere on the board
SPI_MOSI: LCD1.6 (SPI_MOSI), LCD2.6 (SPI_MOSI); also elsewhere on the board
SPI_SCLK: LCD1.5 (SPI_SCLK), LCD2.5 (SPI_SCLK); also elsewhere on the board

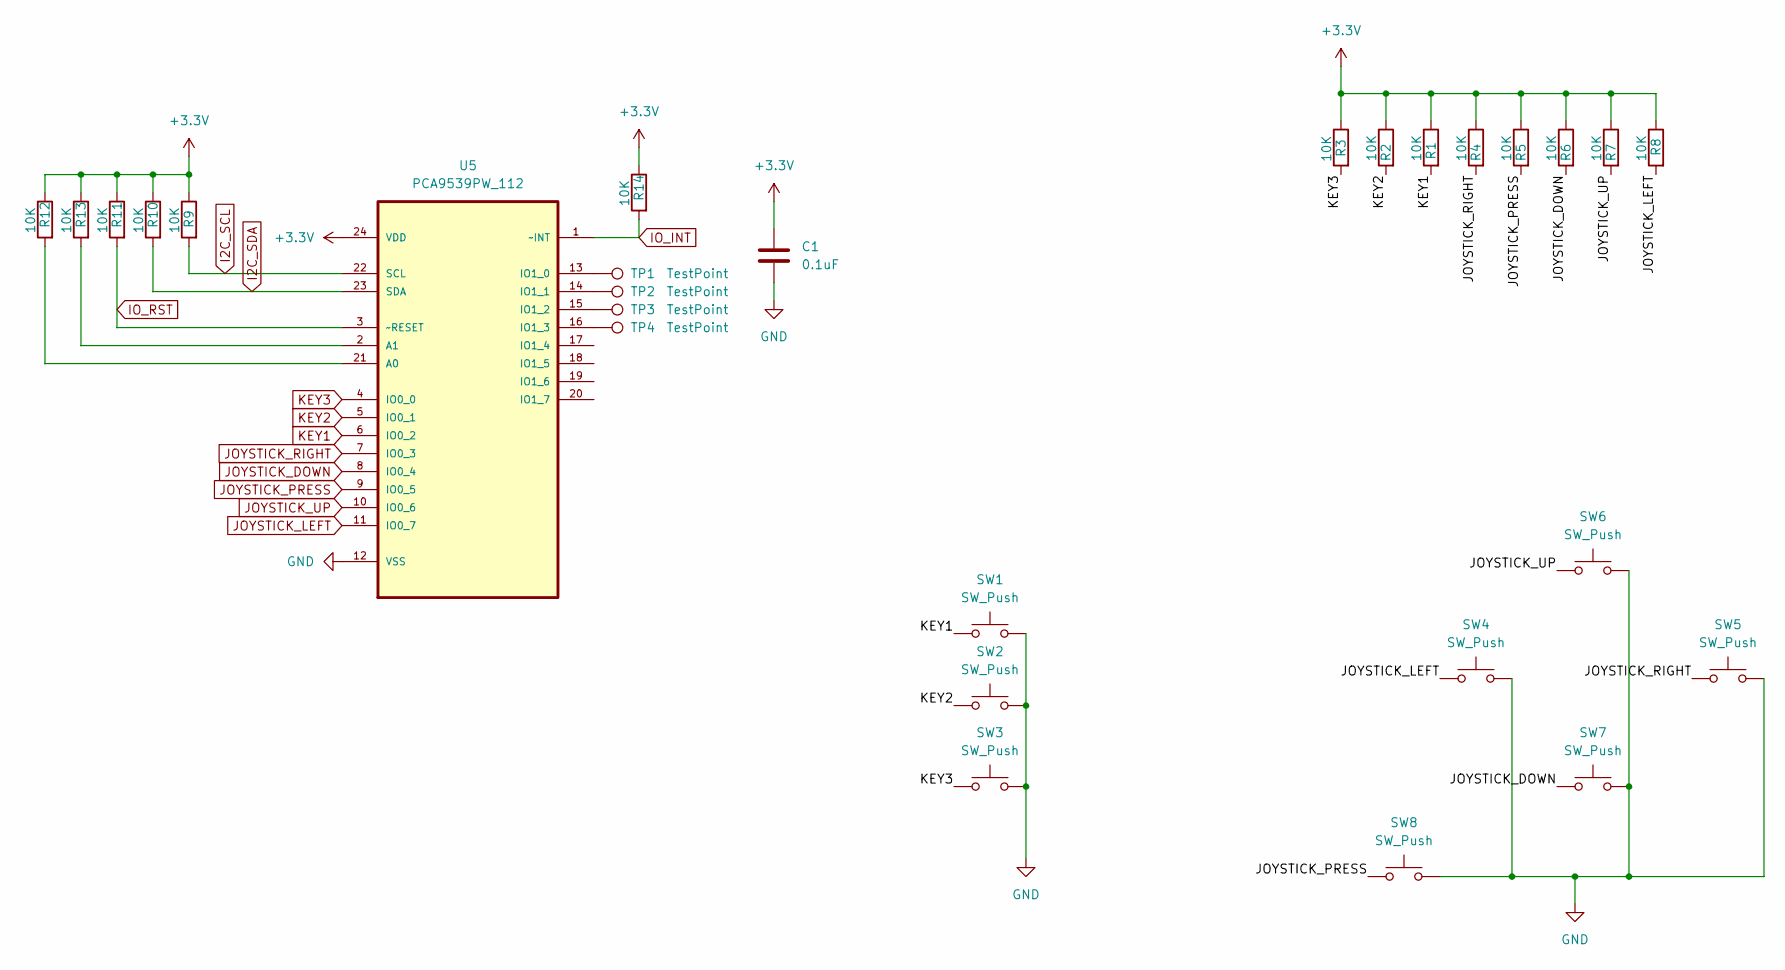
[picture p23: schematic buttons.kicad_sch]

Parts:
C1: 0.1uF; C_0805_2012Metric_Pad1.18x1.45mm_HandSolder
R1, R2, R3, R4, R5, R6, R7, R8, R9, R10, R11, R12, R13, R14: 10K; R_0805_2012Metric_Pad1.20x1.40mm_HandSolder
SW1, SW2, SW3, SW4, SW5, SW6, SW7, SW8: SW_Push; BTN_SPST_NO_PTH
TP1, TP2, TP3, TP4: TestPoint; TestPoint_Pad_D1.0mm
U5: PCA9539PW_112; SOP65P640X110-24N; MPN PCA9539PW,112

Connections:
+3.3V: C1.1, R1.1, R2.1, R3.1, R4.1, R5.1, R6.1, R7.1, R8.1, R9.1, R10.1, R11.1, R12.1, R13.1, R14.1, U5.24 (VDD); also elsewhere on the board
GND: C1.2, SW1.2, SW2.2, SW3.2, SW4.2, SW5.2, SW6.2, SW7.2, SW8.2, U5.12 (VSS); also elsewhere on the board
I2C_SCL: R9.2, U5.22 (SCL); also elsewhere on the board
I2C_SDA: R10.2, U5.23 (SDA); also elsewhere on the board
IO_INT: R14.2, U5.1 (~INT); also elsewhere on the board
IO_RST: R11.2, U5.3 (~RESET); also elsewhere on the board
JOYSTICK_DOWN: R6.2, SW7.1, U5.8 (IO0_4); also elsewhere on the board
JOYSTICK_LEFT: R8.2, SW4.1, U5.11 (IO0_7); also elsewhere on the board
JOYSTICK_PRESS: R5.2, SW8.1, U5.9 (IO0_5); also elsewhere on the board
JOYSTICK_RIGHT: R4.2, SW5.1, U5.7 (IO0_3); also elsewhere on the board
JOYSTICK_UP: R7.2, SW6.1, U5.10 (IO0_6); also elsewhere on the board
KEY1: R1.2, SW1.1, U5.6 (IO0_2); also elsewhere on the board
KEY2: R2.2, SW2.1, U5.5 (IO0_1); also elsewhere on the board
KEY3: R3.2, SW3.1, U5.4 (IO0_0); also elsewhere on the board
unnamed: R12.2, U5.21 (A0)
unnamed: R13.2, U5.2 (A1)
unnamed: TP1.1, U5.13 (IO1_0)
unnamed: TP2.1, U5.14 (IO1_1)
unnamed: TP3.1, U5.15 (IO1_2)
unnamed: TP4.1, U5.16 (IO1_3)

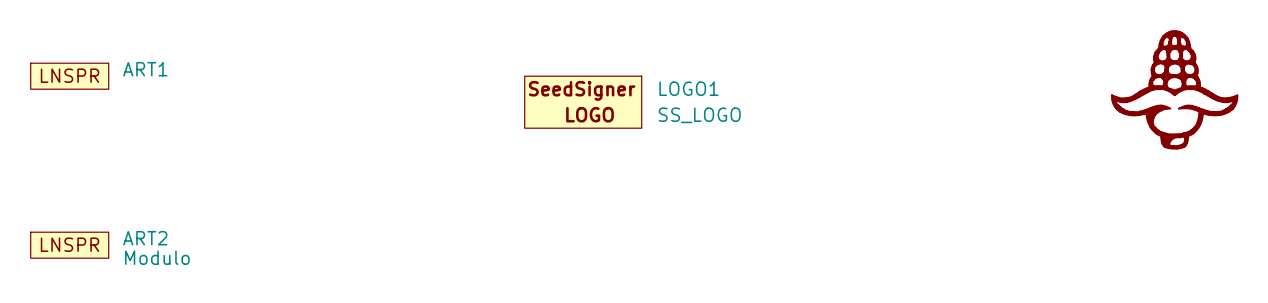
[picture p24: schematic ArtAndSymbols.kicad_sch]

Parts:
ART1: LightningSpore_Logo
ART2: Modulo; modulo-1
LOGO1: SS_LOGO; seedsigner-logo-small
LOGO2: CORN-LOGO; corn-logo

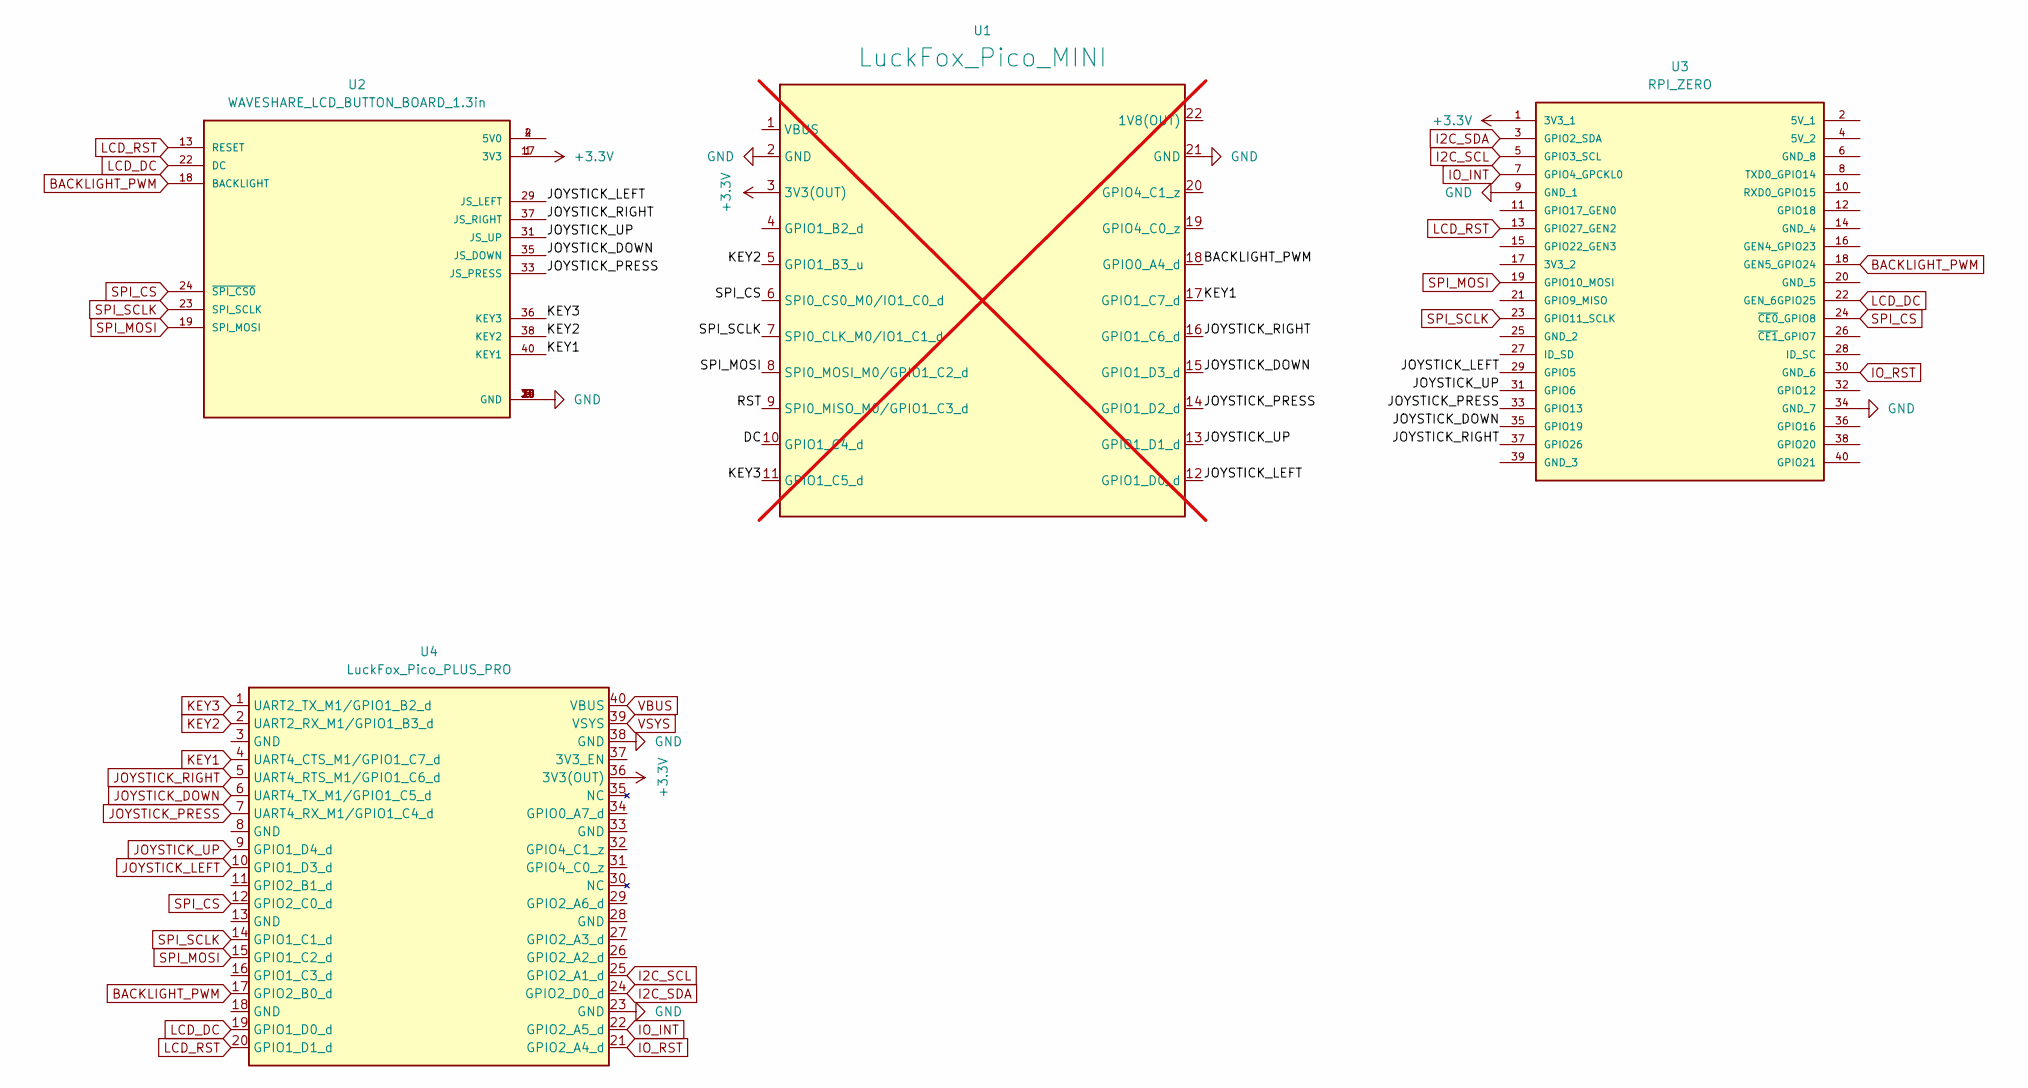
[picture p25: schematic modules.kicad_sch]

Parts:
U1: LuckFox_Pico_MINI; LUCKFOX_PICO_MINI; not fitted
U2: WAVESHARE_LCD_BUTTON_BOARD_1.3in; WAVESHARE_LCD_BUTTON
U3: RPI_ZERO; RPi_Zero
U4: LuckFox_Pico_PLUS_PRO; LUCKFOX_PICO

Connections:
+3.3V: U1.3 (3V3(OUT)), U2.1 (3V3), U2.17 (3V3), U3.1 (3V3_1), U4.36 (3V3(OUT)); also elsewhere on the board
BACKLIGHT_PWM: U2.18 (BACKLIGHT), U3.18 (GEN5_GPIO24), U4.17 (GPIO2_B0_d); also elsewhere on the board
GND: U1.2 (GND), U1.21 (GND), U2.6 (GND), U2.9 (GND), U2.14 (GND), U2.20 (GND), U2.25 (GND), U2.30 (GND), U2.34 (GND), U2.39 (GND), U3.9 (GND_1), U3.34 (GND_7), U4.23 (GND), U4.38 (GND); also elsewhere on the board
I2C_SCL: U3.5 (GPIO3_SCL), U4.25 (GPIO2_A1_d); also elsewhere on the board
I2C_SDA: U3.3 (GPIO2_SDA), U4.24 (GPIO2_D0_d); also elsewhere on the board
IO_INT: U3.7 (GPIO4_GPCKL0), U4.22 (GPIO2_A5_d); also elsewhere on the board
IO_RST: U3.30 (GND_6), U4.21 (GPIO2_A4_d); also elsewhere on the board
JOYSTICK_DOWN: U1.15 (GPIO1_D3_d), U2.35 (JS_DOWN), U3.35 (GPIO19), U4.6 (UART4_TX_M1/GPIO1_C5_d); also elsewhere on the board
JOYSTICK_LEFT: U1.12 (GPIO1_D0_d), U2.29 (JS_LEFT), U3.29 (GPIO5), U4.10 (GPIO1_D3_d); also elsewhere on the board
JOYSTICK_PRESS: U1.14 (GPIO1_D2_d), U2.33 (JS_PRESS), U3.33 (GPIO13), U4.7 (UART4_RX_M1/GPIO1_C4_d); also elsewhere on the board
JOYSTICK_RIGHT: U1.16 (GPIO1_C6_d), U2.37 (JS_RIGHT), U3.37 (GPIO26), U4.5 (UART4_RTS_M1/GPIO1_C6_d); also elsewhere on the board
JOYSTICK_UP: U1.13 (GPIO1_D1_d), U2.31 (JS_UP), U3.31 (GPIO6), U4.9 (GPIO1_D4_d); also elsewhere on the board
KEY1: U1.17 (GPIO1_C7_d), U2.40 (KEY1), U4.4 (UART4_CTS_M1/GPIO1_C7_d); also elsewhere on the board
KEY2: U1.5 (GPIO1_B3_u), U2.38 (KEY2), U4.2 (UART2_RX_M1/GPIO1_B3_d); also elsewhere on the board
KEY3: U1.11 (GPIO1_C5_d), U2.36 (KEY3), U4.1 (UART2_TX_M1/GPIO1_B2_d); also elsewhere on the board
LCD_DC: U2.22 (DC), U3.22 (GEN_6GPIO25), U4.19 (GPIO1_D0_d); also elsewhere on the board
LCD_RST: U2.13 (RESET), U3.13 (GPIO27_GEN2), U4.20 (GPIO1_D1_d); also elsewhere on the board
unnamed: U2.2 (5V0), U2.4 (5V0)
SPI_CS: U2.24 (~SPI_CS0), U3.24 (~CE0_GPIO8), U4.12 (GPIO2_C0_d); also elsewhere on the board
SPI_MOSI: U2.19 (SPI_MOSI), U3.19 (GPIO10_MOSI), U4.15 (GPIO1_C2_d); also elsewhere on the board
SPI_SCLK: U2.23 (SPI_SCLK), U3.23 (GPIO11_SCLK), U4.14 (GPIO1_C1_d); also elsewhere on the board
VBUS: U4.40 (VBUS)
VSYS: U4.39 (VSYS)

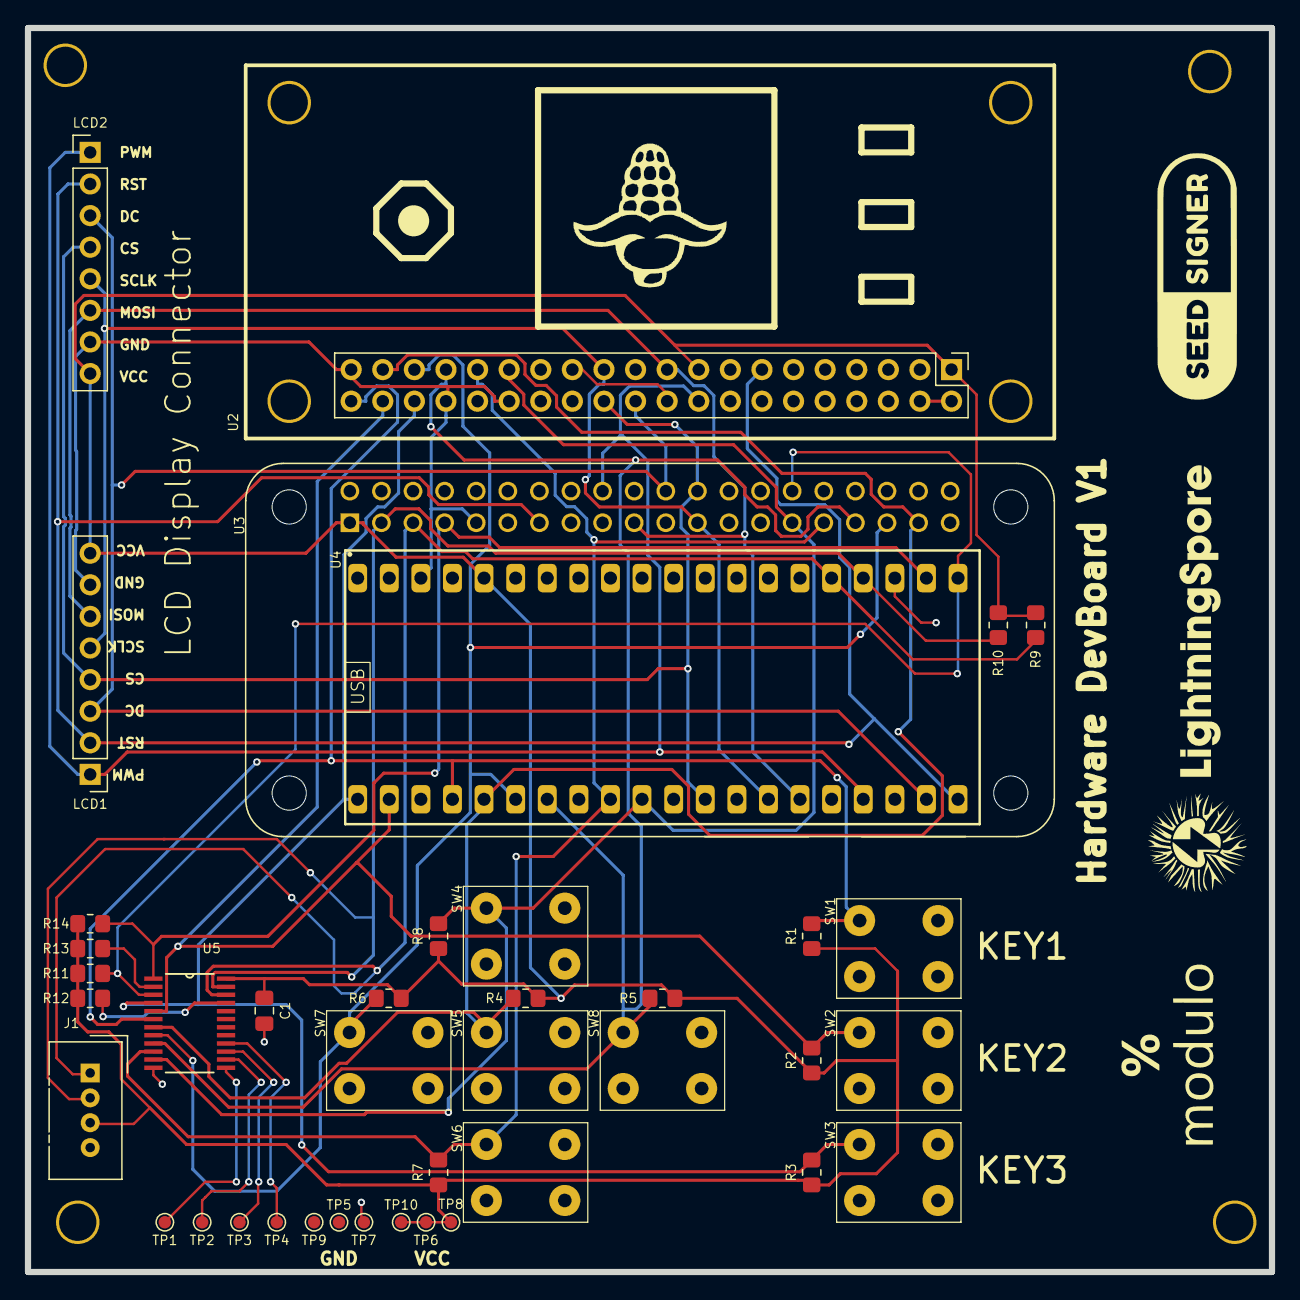
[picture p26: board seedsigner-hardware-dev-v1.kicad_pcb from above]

Board: 2 copper layers, 100.0 x 100.0 mm, 48 parts (0 on the bottom side), 27 nets.

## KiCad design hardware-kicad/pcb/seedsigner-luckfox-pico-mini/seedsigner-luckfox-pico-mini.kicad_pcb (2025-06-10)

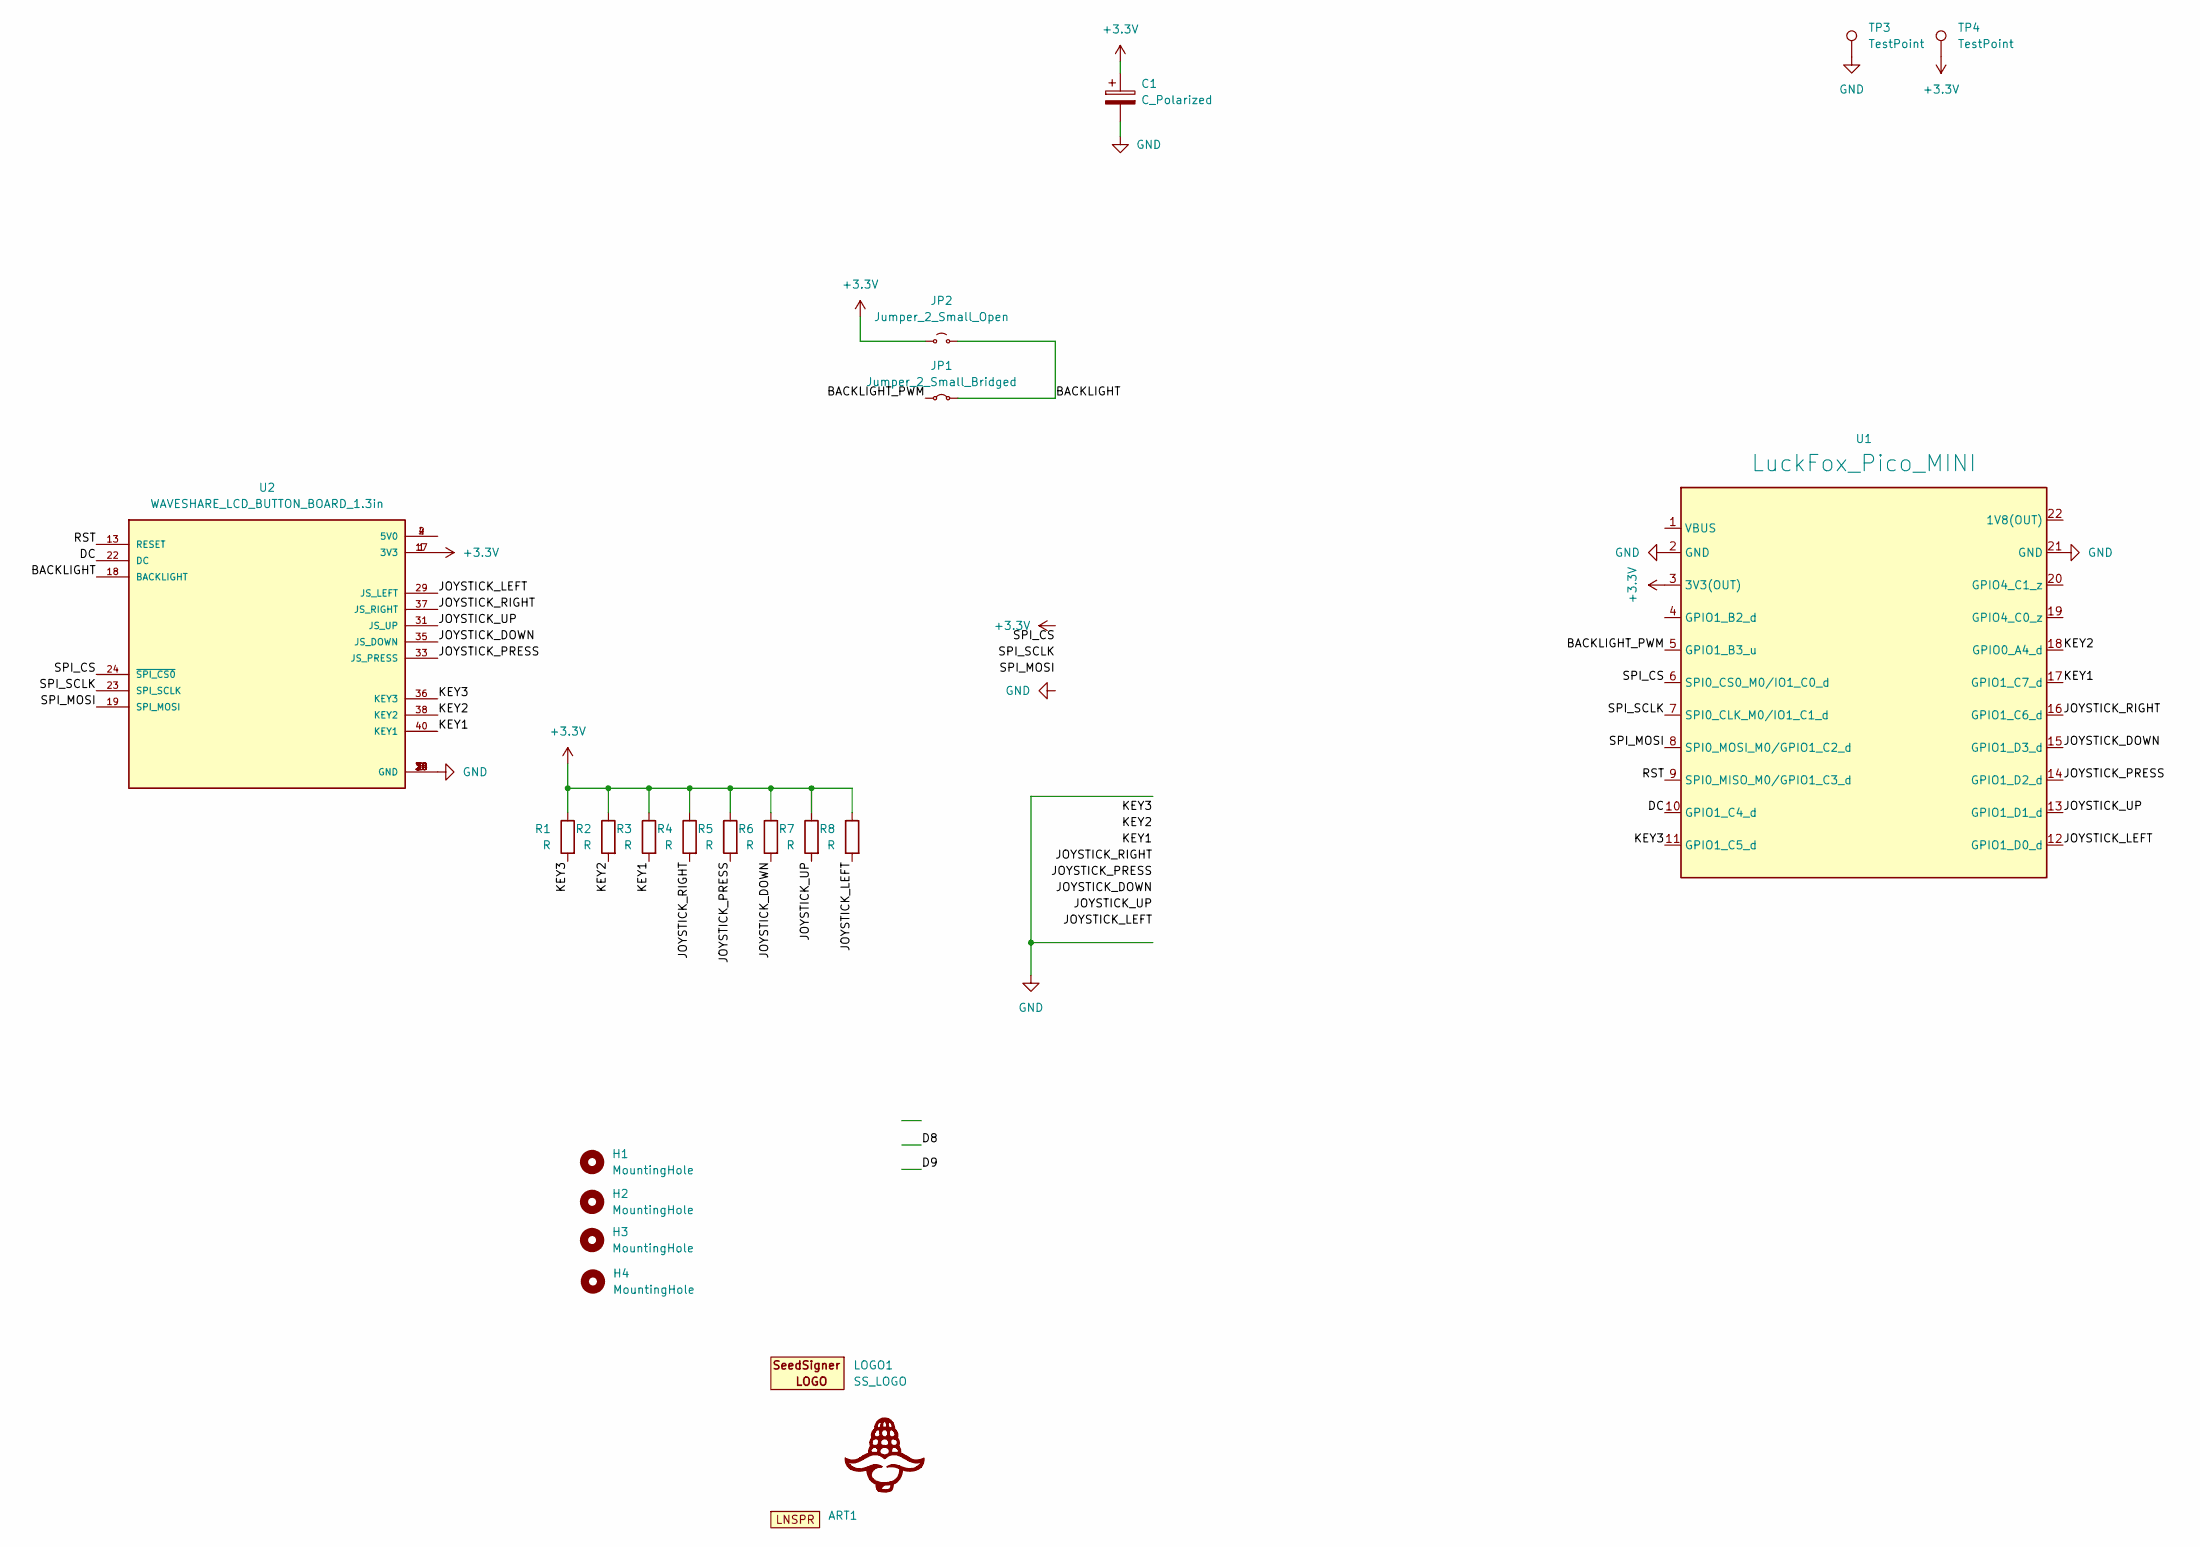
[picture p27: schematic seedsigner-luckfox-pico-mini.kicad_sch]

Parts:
ART1: LightningSpore_Logo
C1: C_Polarized; CP_Radial_D5.0mm_P2.50mm
H1, H2, H3, H4: MountingHole; MOUNT_HOLE_3MM
JP1: Jumper_2_Small_Bridged; SolderJumper-2_P1.3mm_Bridged_Pad1.0x1.5mm
JP2: Jumper_2_Small_Open; SolderJumper-2_P1.3mm_Open_Pad1.0x1.5mm
LOGO1: SS_LOGO; seedsigner-logo-small
LOGO2: CORN-LOGO; corn-logo
R1, R2, R3, R4, R5, R6, R7, R8: R; R_0603_1608Metric_Pad0.98x0.95mm_HandSolder
TP3, TP4: TestPoint; TestPoint_Pad_1.5x1.5mm
U1: LuckFox_Pico_MINI; LUCKFOX_PICO_MINI
U2: WAVESHARE_LCD_BUTTON_BOARD_1.3in; WAVESHARE_LCD_BUTTON

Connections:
+3.3V: C1.1, JP2.1 (A), R1.1, R2.1, R3.1, R4.1, R5.1, R6.1, R7.1, R8.1, TP4.1, U1.3 (3V3(OUT)), U2.1 (3V3), U2.17 (3V3)
/BACKLIGHT: JP1.2 (B), JP2.2 (B), U2.18 (BACKLIGHT)
/BACKLIGHT_PWM: JP1.1 (A), U1.5 (GPIO1_B3_u)
/DC: U1.10 (GPIO1_C4_d), U2.22 (DC)
/JOYSTICK_DOWN: R6.2, U1.15 (GPIO1_D3_d), U2.35 (JS_DOWN)
/JOYSTICK_LEFT: R8.2, U1.12 (GPIO1_D0_d), U2.29 (JS_LEFT)
/JOYSTICK_PRESS: R5.2, U1.14 (GPIO1_D2_d), U2.33 (JS_PRESS)
/JOYSTICK_RIGHT: R4.2, U1.16 (GPIO1_C6_d), U2.37 (JS_RIGHT)
/JOYSTICK_UP: R7.2, U1.13 (GPIO1_D1_d), U2.31 (JS_UP)
/KEY1: R3.2, U1.17 (GPIO1_C7_d), U2.40 (KEY1)
/KEY2: R2.2, U1.18 (GPIO0_A4_d), U2.38 (KEY2)
/KEY3: R1.2, U1.11 (GPIO1_C5_d), U2.36 (KEY3)
/RST: U1.9 (SPI0_MISO_M0/GPIO1_C3_d), U2.13 (RESET)
/SPI_CS: U1.6 (SPI0_CS0_M0/IO1_C0_d), U2.24 (~SPI_CS0)
/SPI_MOSI: U1.8 (SPI0_MOSI_M0/GPIO1_C2_d), U2.19 (SPI_MOSI)
/SPI_SCLK: U1.7 (SPI0_CLK_M0/IO1_C1_d), U2.23 (SPI_SCLK)
GND: C1.2, TP3.1, U1.2 (GND), U1.21 (GND), U2.6 (GND), U2.9 (GND), U2.14 (GND), U2.20 (GND), U2.25 (GND), U2.30 (GND), U2.34 (GND), U2.39 (GND)
unnamed: U2.2 (5V0), U2.4 (5V0)


Board: 2 copper layers, 80.0 x 60.0 mm, 22 parts (0 on the bottom side), 18 nets.

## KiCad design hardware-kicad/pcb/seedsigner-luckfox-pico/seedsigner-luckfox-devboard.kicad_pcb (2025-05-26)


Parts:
ART1: LightningSpore_Logo
C1: C_Polarized; CP_Radial_D5.0mm_P2.50mm
H1, H2, H3, H4: MountingHole; MOUNT_HOLE_3MM
J1: Conn_01x10; PinHeader_1x10_P2.54mm_Horizontal
J2: Conn_01x05; PinHeader_1x05_P2.54mm_Horizontal
JP1: Jumper_2_Small_Bridged; SolderJumper-2_P1.3mm_Bridged_Pad1.0x1.5mm
JP2: Jumper_2_Small_Open; SolderJumper-2_P1.3mm_Open_Pad1.0x1.5mm
LOGO1: SS_LOGO; seedsigner-logo-small
LOGO2: CORN-LOGO; corn-logo
R1, R2, R3, R4, R5, R6, R7, R8: R; R_2512_6332Metric
TP1, TP2, TP3, TP4, TP5, TP6, TP7, TP8, TP9, TP10, TP11, TP12, TP13, TP14, TP15: TestPoint; TestPoint_Pad_1.5x1.5mm
U1: LuckFox_Pico; LUCKFOX_PICO_PRO_MAX_PTH
U2: RASPBERRY_PI_3_MODEL_B+; WAVESHARE_LCD_BUTTON; PARTREV 1.0

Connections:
+3.3V: C1.1, J2.1, JP1.1 (A), R1.1, R2.1, R3.1, R4.1, R5.1, R6.1, R7.1, R8.1, TP4.1, U1.36 (3V3(OUT)), U2.1 (3V3), U2.17 (3V3)
/BACKLIGHT: JP1.2 (B), JP2.2 (B), U2.18 (GPIO24/GPIO_GEN5)
/BACKLIGHT_PWM: JP2.1 (A), U1.17 (GPIO2_B0_d)
/DC: U1.19 (GPIO1_D0_d), U2.22 (GPIO25/GPIO_GEN6)
/JOYSTICK_DOWN: J1.7, R6.2, U1.6 (UART4_TX_M1/GPIO1_C5_d), U2.35 (GPIO19)
/JOYSTICK_LEFT: J1.9, R8.2, U1.10 (GPIO1_D3_d), U2.29 (GPIO5)
/JOYSTICK_PRESS: J1.6, R5.2, U1.7 (UART4_RX_M1/GPIO1_C4_d), U2.33 (GPIO13)
/JOYSTICK_RIGHT: J1.5, R4.2, U1.5 (UART4_RTS_M1/GPIO1_C6_d), U2.37 (GPIO26)
/JOYSTICK_UP: J1.8, R7.2, U1.9 (GPIO1_D4_d), U2.31 (GPIO6)
/KEY1: J1.4, R3.2, U1.4 (UART4_CTS_M1/GPIO1_C7_d), U2.40 (GPIO21)
/KEY2: J1.3, R2.2, U1.2 (UART2_RX_M1/GPIO1_B3_d), U2.38 (GPIO20)
/KEY3: J1.2, R1.2, U1.1 (UART2_TX_M1/GPIO1_B2_d), U2.36 (GPIO16)
/RST: U1.20 (GPIO1_D1_d), U2.13 (GPIO27/GPIO_GEN2)
/SPI_CS: J2.2, U1.12 (GPIO2_C0_d), U2.24 (GPIO8/~SPI_CE0)
/SPI_MOSI: J2.4, U1.15 (GPIO1_C2_d), U2.19 (GPIO10/SPI_MOSI)
/SPI_SCLK: J2.3, U1.14 (GPIO1_C1_d), U2.23 (GPIO11/SPI_SCLK)
GND: C1.2, J1.1, J1.10, J2.5, TP3.1, U1.18 (GND), U1.38 (GND), U2.6 (GND), U2.9 (GND), U2.14 (GND), U2.20 (GND), U2.25 (GND), U2.30 (GND), U2.34 (GND), U2.39 (GND)
unnamed: TP15.1, U1.34 (GPIO0_A7_d)
unnamed: TP5.1, U1.16 (GPIO1_C3_d)
unnamed: TP9.1, U1.25 (GPIO2_A1_d)
unnamed: TP10.1, U1.26 (GPIO2_A2_d)
unnamed: TP11.1, U1.27 (GPIO2_A3_d)
unnamed: TP6.1, U1.21 (GPIO2_A4_d)
unnamed: TP7.1, U1.22 (GPIO2_A5_d)
unnamed: TP12.1, U1.29 (GPIO2_A6_d)
unnamed: TP8.1, U1.24 (GPIO2_D0_d)
unnamed: TP13.1, U1.31 (GPIO4_C0_z)
unnamed: TP14.1, U1.32 (GPIO4_C1_z)
unnamed: TP1.1, U1.40 (VBUS)
unnamed: TP2.1, U1.39 (VSYS)
unnamed: U2.2 (5V0), U2.4 (5V0)


Board: 2 copper layers, 100.0 x 100.0 mm, 37 parts (0 on the bottom side), 31 nets.

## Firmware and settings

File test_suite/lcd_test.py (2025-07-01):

#!/usr/bin/env python3

import sys
import os
import time
import platform
from PIL import Image, ImageDraw

# Add the seedsigner src directory to the path
sys.path.insert(0, os.path.join(os.path.dirname(__file__), '..', 'seedsigner'))

# Monkey patch the Settings class to use our custom settings file
from seedsigner.models.settings import Settings
Settings.SETTINGS_FILENAME = "/seedsigner/settings.json"

from seedsigner.gui.renderer import Renderer
from seedsigner.models.settings_definition import SettingsConstants

def initialize_renderer():
    """Initialize the renderer once for all tests"""
    try:
        Renderer.configure_instance()
        return Renderer.get_instance()
    except Exception as e:
        print(f"Failed to initialize renderer: {e}")
        return None

def test_lcd_initialization():
    """Test that LCD can be initialized"""
    print("Testing LCD initialization...")
    try:
        renderer = Renderer.get_instance()
        print("✓ LCD initialized successfully")
        return True
    except Exception as e:
        print(f"✗ Failed to initialize LCD: {e}")
        return False

def test_display_settings():
    """Test and display current LCD settings"""
    print("\nTesting display settings...")
    try:
        settings = Settings.get_instance()
        
        # Get display configuration
        display_config = settings.get_value(SettingsConstants.SETTING__DISPLAY_CONFIGURATION, default_if_none=True)
        print(f"✓ Display config: {display_config}")
        
        # Get hardware configuration
        hardware_config = settings.get_value(SettingsConstants.SETTING__HARDWARE_CONFIG)
        print(f"✓ Hardware config: {hardware_config}")
        
        # Get color inversion setting
        color_inverted = settings.get_value(SettingsConstants.SETTING__DISPLAY_COLOR_INVERTED, default_if_none=True)
        print(f"✓ Color inverted: {color_inverted}")
        
        return True
    except Exception as e:
        print(f"✗ Display settings test failed: {e}")
        return False

def test_display_dimensions():
    """Test and display LCD dimensions"""
    print("\nTesting display dimensions...")
    try:
        # Get the already configured renderer instance
        renderer = Renderer.get_instance()
        
        print(f"✓ Canvas width: {renderer.canvas_width}")
        print(f"✓ Canvas height: {renderer.canvas_height}")
        print(f"✓ Display type: {renderer.display_type}")
        
        return True
    except Exception as e:
        print(f"✗ Display dimensions test failed: {e}")
        return False

def create_flag_image(width, height, flag_type):
    """Create a simple flag image using PIL"""
    img = Image.new('RGB', (width, height))
    draw = ImageDraw.Draw(img)
    
    if flag_type == "france":
        # French flag: blue, white, red vertical stripes
        third = width // 3
        draw.rectangle([0, 0, third, height], fill=(0, 85, 164))  # Blue
        draw.rectangle([third, 0, 2*third, height], fill=(255, 255, 255))  # White
        draw.rectangle([2*third, 0, width, height], fill=(239, 65, 53))  # Red
        
    elif flag_type == "germany":
        # German flag: black, red, gold horizontal stripes
        third = height // 3
        draw.rectangle([0, 0, width, third], fill=(0, 0, 0))  # Black
        draw.rectangle([0, third, width, 2*third], fill=(221, 0, 0))  # Red
        draw.rectangle([0, 2*third, width, height], fill=(255, 206, 0))  # Gold
        
    elif flag_type == "italy":
        # Italian flag: green, white, red vertical stripes
        third = width // 3
        draw.rectangle([0, 0, third, height], fill=(0, 146, 70))  # Green
        draw.rectangle([third, 0, 2*third, height], fill=(255, 255, 255))  # White
        draw.rectangle([2*third, 0, width, height], fill=(206, 43, 55))  # Red
        
    elif flag_type == "japan":
        # Japanese flag: white background with red circle
        draw.rectangle([0, 0, width, height], fill=(255, 255, 255))  # White background
        circle_radius = min(width, height) // 3
        circle_x = width // 2
        circle_y = height // 2
        draw.ellipse([circle_x - circle_radius, circle_y - circle_radius, 
                     circle_x + circle_radius, circle_y + circle_radius], 
                    fill=(188, 0, 45))  # Red circle
        
    elif flag_type == "usa":
        # Simplified US flag: red and white stripes with blue canton
        stripe_height = height // 13
        for i in range(13):
            y_start = i * stripe_height
            y_end = (i + 1) * stripe_height
            if i % 2 == 0:  # Red stripes
                draw.rectangle([0, y_start, width, y_end], fill=(179, 25, 66))
            else:  # White stripes
                draw.rectangle([0, y_start, width, y_end], fill=(255, 255, 255))
        
        # Blue canton (top left)
        canton_width = width // 2
        canton_height = height // 2
        draw.rectangle([0, 0, canton_width, canton_height], fill=(10, 49, 97))
    
    return img

def test_flag_display():
    """Test displaying different flag images on the LCD"""
    print("\nTesting flag display...")
    try:
        # Get the already configured renderer instance
        renderer = Renderer.get_instance()
        flags = ["france", "germany", "italy", "japan", "usa"]
        
        for i, flag_type in enumerate(flags, 1):
            print(f"Displaying {flag_type} flag ({i}/5)...")
            
            # Create flag image
            flag_img = create_flag_image(renderer.canvas_width, renderer.canvas_height, flag_type)
            
            # Display the flag
            renderer.show_image(flag_img, show_direct=True)
            
            # Wait a bit to see the flag
            time.sleep(2)
        
        print("✓ All flags displayed successfully")
        return True
    except Exception as e:
        print(f"✗ Flag display test failed: {e}")
        return False

def test_color_display():
    """Test displaying different colors on the LCD"""
    print("\nTesting color display...")
    try:
        # Get the already configured renderer instance
        renderer = Renderer.get_instance()
        colors = [
            ("Red", (255, 0, 0)),
            ("Green", (0, 255, 0)),
            ("Blue", (0, 0, 255)),
            ("White", (255, 255, 255)),
            ("Black", (0, 0, 0)),
            ("Yellow", (255, 255, 0)),
            ("Cyan", (0, 255, 255)),
            ("Magenta", (255, 0, 255))
        ]
        
        for color_name, color_rgb in colors:
            print(f"Displaying {color_name}...")
            
            # Create solid color image
            color_img = Image.new('RGB', (renderer.canvas_width, renderer.canvas_height), color_rgb)
            
            # Display the color
            renderer.show_image(color_img, show_direct=True)
            
            # Wait a bit to see the color
            time.sleep(1)
        
        print("✓ All colors displayed successfully")
        return True
    except Exception as e:
        print(f"✗ Color display test failed: {e}")
        return False

def test_pattern_display():
    """Test displaying patterns on the LCD"""
    print("\nTesting pattern display...")
    try:
        # Get the already configured renderer instance
        renderer = Renderer.get_instance()
        
        # Create a checkerboard pattern
        print("Displaying checkerboard pattern...")
        pattern_img = Image.new('RGB', (renderer.canvas_width, renderer.canvas_height))
        draw = ImageDraw.Draw(pattern_img)
        
        square_size = 20
        for x in range(0, renderer.canvas_width, square_size):
            for y in range(0, renderer.canvas_height, square_size):
                if (x // square_size + y // square_size) % 2 == 0:
                    draw.rectangle([x, y, x + square_size, y + square_size], fill=(255, 255, 255))
                else:
                    draw.rectangle([x, y, x + square_size, y + square_size], fill=(0, 0, 0))
        
        renderer.show_image(pattern_img, show_direct=True)
        time.sleep(3)
        
        # Create a gradient pattern
        print("Displaying gradient pattern...")
        gradient_img = Image.new('RGB', (renderer.canvas_width, renderer.canvas_height))
        draw = ImageDraw.Draw(gradient_img)
        
        for x in range(renderer.canvas_width):
            for y in range(renderer.canvas_height):
                r = int((x / renderer.canvas_width) * 255)
                g = int((y / renderer.canvas_height) * 255)
                b = 128
                draw.point((x, y), fill=(r, g, b))
        
        renderer.show_image(gradient_img, show_direct=True)
        time.sleep(3)
        
        print("✓ All patterns displayed successfully")
        return True
    except Exception as e:
        print(f"✗ Pattern display test failed: {e}")
        return False

def test_text_display():
    """Test displaying text on the LCD"""
    print("\nTesting text display...")
    try:
        # Get the already configured renderer instance
        renderer = Renderer.get_instance()
        
        # Create a test image with text
        text_img = Image.new('RGB', (renderer.canvas_width, renderer.canvas_height), (0, 0, 0))
        draw = ImageDraw.Draw(text_img)
        
        # Try to use a basic font, fallback to default if not available
        try:
            from PIL import ImageFont
            font = ImageFont.truetype("/usr/share/fonts/truetype/dejavu/DejaVuSans-Bold.ttf", 20)
        except:
            font = ImageFont.load_default()
        
        # Draw some test text
        text_lines = [
            "LCD Test",
            f"Size: {renderer.canvas_width}x{renderer.canvas_height}",
            "Display Working!",
            "Flags: France, Germany,",
            "Italy, Japan, USA"
        ]
        
        y_offset = 20
        for line in text_lines:
            draw.text((10, y_offset), line, fill=(255, 255, 255), font=font)
            y_offset += 30
        
        renderer.show_image(text_img, show_direct=True)
        time.sleep(3)
        
        print("✓ Text display test successful")
        return True
    except Exception as e:
        print(f"✗ Text display test failed: {e}")
        return False

def test_blank_screen():
    """Test displaying a blank screen"""
    print("\nTesting blank screen...")
    try:
        # Get the already configured renderer instance
        renderer = Renderer.get_instance()
        renderer.display_blank_screen()
        print("✓ Blank screen displayed successfully")
        return True
    except Exception as e:
        print(f"✗ Blank screen test failed: {e}")
        return False

def main():
    print("=== LCD Display Test Script ===\n")
    
    # Initialize the renderer once at the beginning
    print("Initializing renderer...")
    renderer = initialize_renderer()
    if renderer is None:
        print("✗ Failed to initialize renderer. Exiting.")
        return 1
    
    tests = [
        test_lcd_initialization,
        test_display_settings,
        test_display_dimensions,
        test_color_display,
        test_pattern_display,
        test_flag_display,
        test_text_display,
        test_blank_screen
    ]
    
    passed = 0
    total = len(tests)
    
    for test in tests:
        if test():
            passed += 1
        print()
    
    print(f"=== Test Results ===")
    print(f"Passed: {passed}/{total}")
    
    if passed == total:
        print("✓ All tests passed!")
        return 0
    else:
        print("✗ Some tests failed!")
        return 1

if __name__ == "__main__":
    sys.exit(main())

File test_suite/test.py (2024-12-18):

import os
import struct
import time
from periphery import GPIO
from hardware.ST7789 import ST7789
from PIL import Image, ImageDraw, ImageFont


# Set up the V4L2 device and capture configuration
CAMERA_DEVICE = '/dev/video15'
WIDTH = 240
HEIGHT = 135
PIXEL_FORMAT = 'NV12'  # Y/CbCr 4:2:0 format
FRAME_SIZE = 48480  # This is the size of one frame in bytes

# Define button pins
pins = [
    ("KEY2", GPIO(43, "in")),  # KEY 2
    ("KEY1", GPIO(55, "in")),  # KEY 1 
    ("RIGHT", GPIO(54, "in")),  # RIGHT
    ("DOWN", GPIO(53, "in")),  # DOWN
    ("IN", GPIO(52, "in")),  # IN (Push directional button in)
    ("UP", GPIO(58, "in")),  # UP
    ("LEFT", GPIO(59, "in")),  # LEFT
    ("KEY3", GPIO(42, "in")),  # KEY 3 Back Button (Always pressed?)
]
#    

# Initialize the LCD display
disp = ST7789()
width, height = 240, 240  # LCD resolution


def capture_frame():
    """
    Captures one frame from the camera using v4l2-ctl.
    """
    # Ensure the output file doesn't already exist
    if os.path.exists('frame.yuv'):
        os.remove('frame.yuv')
    
    cmd = f'v4l2-ctl --device={CAMERA_DEVICE} --set-fmt-video=width={WIDTH},height={HEIGHT},pixelformat={PIXEL_FORMAT} --stream-mmap --stream-to=frame.yuv --stream-count=1'
    print(f"Executing command: {cmd}")
    
    # Use os.system to run the command and capture potential errors
    result = os.system(cmd)
    print(f"v4l2-ctl command exit status: {result}")
    
    # Check if file was created
    if not os.path.exists('frame.yuv'):
        raise ValueError("Failed to capture frame. No output file created.")
    
    with open('frame.yuv', 'rb') as file:
        frame_data = file.read()
    
    print(f"Captured frame size: {len(frame_data)} bytes")
    
    # Some additional sanity checks
    if len(frame_data) == 0:
        raise ValueError("Captured frame is empty!")
    
    return frame_data


def convert_nv12_to_rgb(frame_data):
    """
    Converts NV12 frame data to an RGB image with improved error handling.
    """
    WIDTH = 240
    HEIGHT = 135
    
    # Precise frame size calculations
    y_size = WIDTH * HEIGHT  # Luma (Y) plane size
    uv_width = (WIDTH + 1) // 2  # Chroma plane width
    uv_height = (HEIGHT + 1) // 2  # Chroma plane height
    uv_size = uv_width * uv_height * 2  # UV plane size (interleaved U and V)
    
    # Slice the planes, being careful about exact sizes
    y_plane = frame_data[:y_size]
    uv_plane = frame_data[y_size:y_size + uv_size]
    
    # Ensure we use the minimum of the actual data and expected sizes
    effective_y_size = min(len(y_plane), y_size)
    effective_uv_size = min(len(uv_plane), uv_size)
    
    rgb_data = bytearray()
    
    for i in range(HEIGHT):
        for j in range(WIDTH):
            y_index = i * WIDTH + j
            uv_index = (i // 2) * uv_width + (j // 2)
            
            # Robust bounds checking
            if y_index >= effective_y_size:
                # If Y index is out of bounds, use black
                r, g, b = 0, 0, 0
            else:
                # Get Y value
                y = y_plane[y_index]
                
                # Carefully handle UV indices
                if uv_index * 2 + 1 >= effective_uv_size:
                    # If UV index is out of bounds, use neutral gray for chroma
                    u, v = 0, 0
                else:
                    u = uv_plane[2 * uv_index] - 128
                    v = uv_plane[2 * uv_index + 1] - 128
                
                # YUV to RGB conversion with clamping
                r = max(0, min(255, int(y + 1.402 * v)))
                g = max(0, min(255, int(y - 0.344136 * u - 0.714136 * v)))
                b = max(0, min(255, int(y + 1.772 * u)))
            
            rgb_data.extend([r, g, b])
    
    return rgb_data



def display_on_lcd(rgb_data):
    """
    Display the frame on the LCD screen using PIL Image.
    """
    try:
        # Create a PIL Image from the raw RGB data
        img = Image.frombytes('RGB', (WIDTH, HEIGHT), bytes(rgb_data))
        
        # If the display resolution is different, resize to fit
        img = img.resize((width, height))
        
        # Display the image on the LCD
        disp.ShowImage(img, 0, 0)
    except Exception as e:
        print(f"Failed to display image: {e}")


def display_message(text, display_time = 2):
    """
    Display a message on the image display with Unicode and encoding safeguards.
    
    Args:
    text (str): The message to display
    """
    # Create a blank image with RGB mode
    img = Image.new('RGB', (width, height), (0, 0, 0))  # Black background
    draw = ImageDraw.Draw(img)
    
    # Load a Font
    #font = ImageFont.load_default()
    font = ImageFont.truetype("/test_suite/Poppins-Regular.otf", 16)
    
    # Sanitize text: replace or remove problematic Unicode characters
    # This ensures we only use ASCII or easily encodable characters
    safe_text = ''.join(char if ord(char) < 128 else ' ' for char in text)
    
    # Use textbbox to get text dimensions
    text_bbox = draw.textbbox((0, 0), safe_text, font=font)
    
    # Calculate text width and height from bounding box
    text_width = text_bbox[2] - text_bbox[0]
    text_height = text_bbox[3] - text_bbox[1]
    
    # Center the text
    x = (width - text_width) // 2
    y = (height - text_height) // 2
    
    # Draw the text
    draw.text((x, y), safe_text, font=font, fill=(255, 255, 255))  # White text
    disp.ShowImage(img, 0, 0)

    # Wait for specified display time
    time.sleep(display_time)




def button_test():
    """Test each button on the device."""
    results = {}
    for name, pin in pins:
        display_message(f"Press {name} button", 0.5)
        start_time = time.time()
        while True:
            if not pin.read():  # Button is pressed (active low)
                results[name] = True
                display_message(f"{name} Button OK ✓", 1.5)
                time.sleep(0.5)  # Debounce
                while not pin.read():
                    pass  # Wait until released
                break
            elif time.time() - start_time > 10:  # 10-second timeout
                display_message(f"{name} Button NOT pressed (timeout)")
                results[name] = False
                break
            time.sleep(0.1)
    return results



def camera_test():
    """Test the camera by capturing a frame and displaying it."""
    try:
        display_message("Testing Camera...")
        frame_data = capture_frame()
        display_message("Converting to RGB...")
        rgb_data = convert_nv12_to_rgb(frame_data)
        display_on_lcd(rgb_data)
        time.sleep(2)
        return True
    except Exception as e:
        display_message(f"Camera Error: {str(e)}")
        return False
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

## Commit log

2024-12-05 add kicad test-harness design files
    [seedsigner-luckfox-pico.kicad_pcb, seedsigner-luckfox-pico.kicad_sch]
2024-12-05 hardware config
    [luckfox.cfg]
2024-12-17 Properly Mapped Buttons
    test_buttons_lcd.py Is a new script that will display the buttons name on the lcd when pressed.
2024-12-17 Camera to LCD success
    test_all.py successfully takes a picture when the KEY1 button is pressed then displays the picture on the LCD screen
2024-12-17 UX test completed
    UX test called test.py is a script that allows user to test all buttons, camera, and exit test.
2025-03-23 further automatic setup of the OS build
    install the pin config and copy over seedsigner code
    when entering the container setup the environment so we can directly start doing buildroot
2025-03-23 Update readme with images of the prototype device
2025-03-23 Add BOM with total costs and demo video link
2025-05-15 fix kicad files and upload gerbers
    [seedsigner-luckfox-devboard.kicad_pcb, seedsigner-luckfox-devboard.kicad_sch, seedsigner-luckfox-pico.kicad_pcb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]
2025-05-15 export footprint library pretty files, and update pcb to use library
    [seedsigner-luckfox-devboard.kicad_pcb]
2025-05-15 Add luckfox 3d models and start Luckfox pico mini footprint
2025-05-15 update libraries and make schematic and pcb only use parts from library
    [seedsigner-luckfox-devboard.kicad_pcb, seedsigner-luckfox-devboard.kicad_sch]
2025-05-15 update the sch/pcb to kiCAD 9
    [seedsigner-luckfox-devboard.kicad_pcb, seedsigner-luckfox-devboard.kicad_sch]
2025-05-16 restructure dir structure and start luckfox-pico-mini pcb
    [seedsigner-luckfox-pico-mini.kicad_pcb, seedsigner-luckfox-pico-mini.kicad_sch]
2025-05-17 add waveshare lcd 3d model and initial pcb routing
    [seedsigner-luckfox-pico-mini.kicad_pcb, seedsigner-luckfox-pico-mini.kicad_sch]
2025-05-26 restart pcb from backup
    [seedsigner-luckfox-devboard.kicad_pcb, seedsigner-luckfox-devboard.kicad_sch]
2025-05-26 auto-route and cleanup of pico mini devboard
    [seedsigner-luckfox-devboard.kicad_sch, seedsigner-luckfox-pico-mini.kicad_pcb, seedsigner-luckfox-pico-mini.kicad_sch]
2025-05-26 add pdf schematic of pico pro max dev board
2025-05-27 finalize luckfox pico mini design
    [seedsigner-luckfox-pico-mini.kicad_pcb]
2025-05-27 waveshare lcd+button hat 3d models
    [WaveShare 1.44inch LCD HAT v1.step, waveshare_lcd_hat.stl]
2025-05-27 commit gerbers and last mods of luckfox mini pcb
    [seedsigner-luckfox-pico-mini.kicad_pcb]
2025-06-10 cleanup project paths and make sure symbols and footprints are committed
    [seedsigner-luckfox-pico-mini.kicad_pcb, seedsigner-luckfox-pico-mini.kicad_sch]
2025-06-18 Add RPi Zero footprint to library
2025-06-18 start seedsigner-hardware-dev-v1 PCB
    [seedsigner-hardware-dev-v1.kicad_pcb, seedsigner-hardware-dev-v1.kicad_sch]
2025-06-18 seedsigner hardware dev v1 all footprints created and placed
    [buttons.kicad_sch, seedsigner-hardware-dev-v1.kicad_pcb, seedsigner-hardware-dev-v1.kicad_sch]
2025-06-19 hardware devboard changes and footprints for LCD screens
    [seedsigner-hardware-dev-v1.dsn, seedsigner-hardware-dev-v1.kicad_pcb]
2025-06-23 use hierarchical sheets in kicad
    [ArtAndSymbols.kicad_sch, buttons.kicad_sch, seedsigner-hardware-dev-v1.kicad_pcb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]
2025-06-23 luckfox pico mini photos
2025-06-30 update library paths and modularize sch
    [modules.kicad_sch, seedsigner-hardware-dev-v1.kicad_pcb, seedsigner-hardware-dev-v1.kicad_sch]
2025-06-30 autoroute the hardware devboard
    [seedsigner-hardware-dev-v1.dsn, seedsigner-hardware-dev-v1.kicad_pcb, seedsigner-hardware-dev-v1.kicad_sch]
2025-07-01 Kicad work related to new PCB
    [ArtAndSymbols.kicad_sch, buttons.kicad_sch, modules.kicad_sch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]
2025-07-03 test suite: record camera capture
2025-07-08 2 different pcbs almost done
    [buttons.kicad_sch, modules.kicad_sch, seedsigner-hardware-dev-v1.kicad_pcb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]
2025-07-08 close to ordering on jlcpcb
    [ArtAndSymbols.kicad_sch, BOM-seedsigner-hardware-dev-v1.csv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]
2025-07-26 pcb checkin, ordered
    [ArtAndSymbols.kicad_sch, BOM-seedsigner-hardware-dev-v1.csv, buttons.kicad_sch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]
